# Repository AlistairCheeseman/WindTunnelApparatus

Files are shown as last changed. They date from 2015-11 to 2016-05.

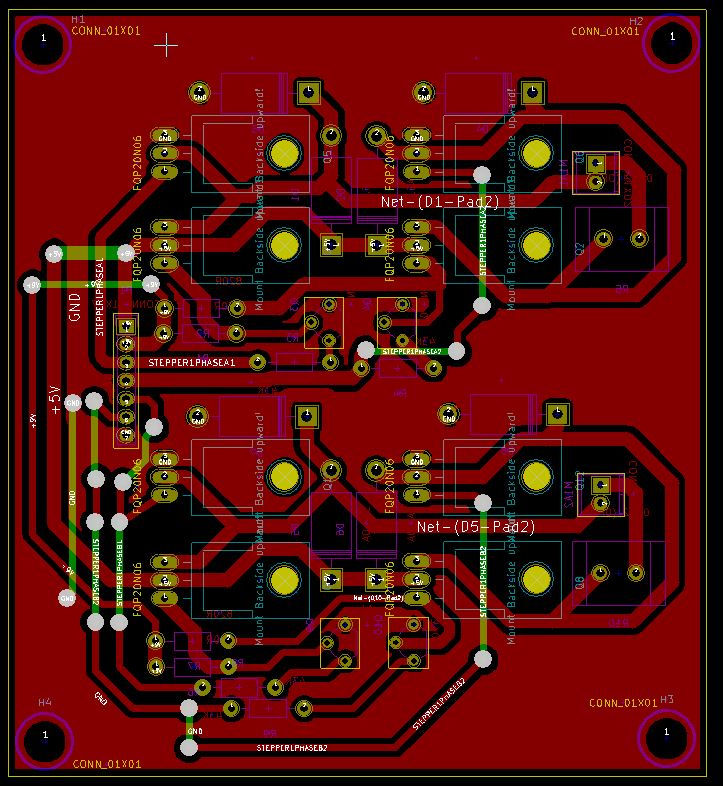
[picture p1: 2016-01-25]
Hardware/StepperDriver/Driver/Driver-PCB.JPG

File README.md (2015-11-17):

# WindTunnelApparatus
MENG Data Acquisition + motion control for Wind Tunnel Apparatus Project

There are three root folders in this repository:

Hardware  -  Contains hardware designs, files are created in KiCAD however relevant pdfs are provided.

Software  -  Contains software used on the Acquisition Computer

Firmware  -  Contains firmware source code, self explanatory

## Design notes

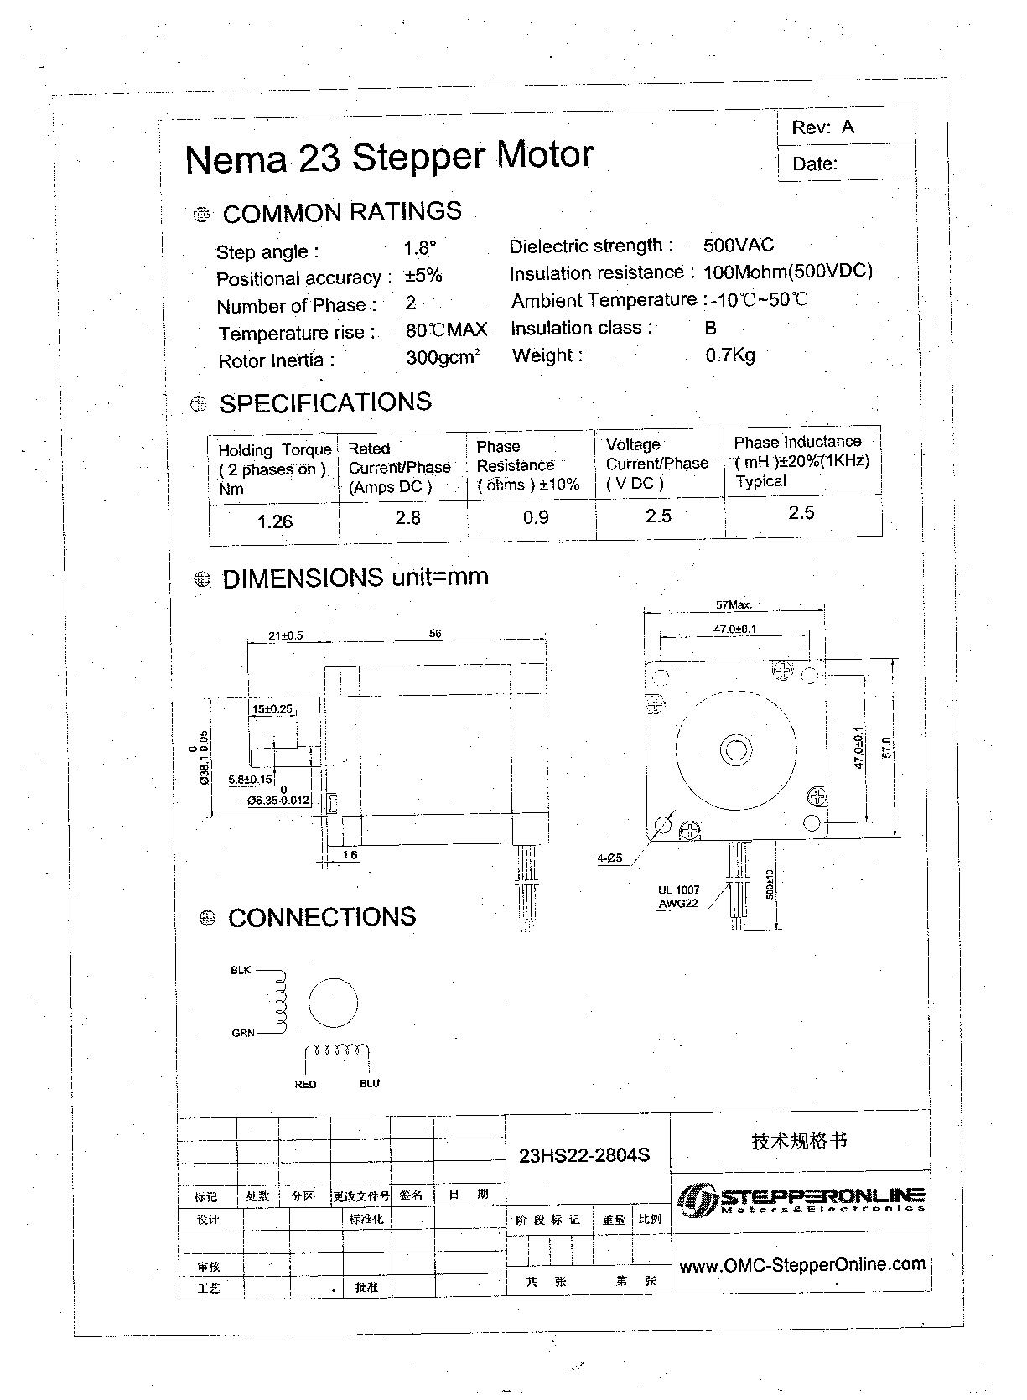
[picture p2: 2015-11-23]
Hardware/Datasheets/stepper.jpeg

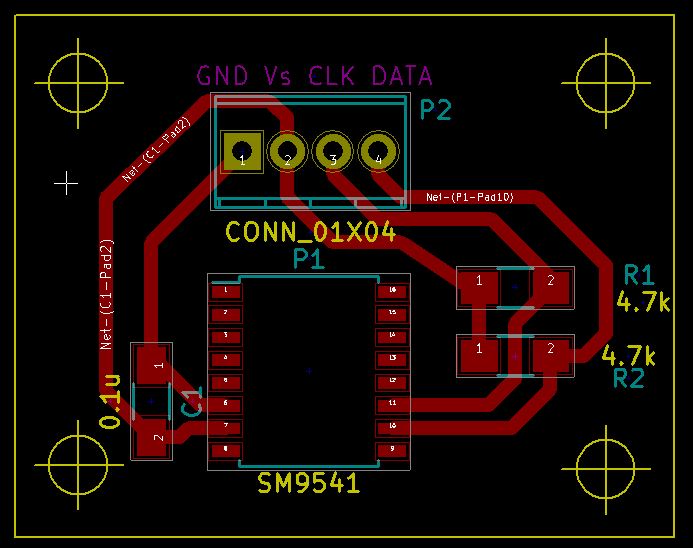
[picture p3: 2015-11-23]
Hardware/I2C/Rev2.JPG

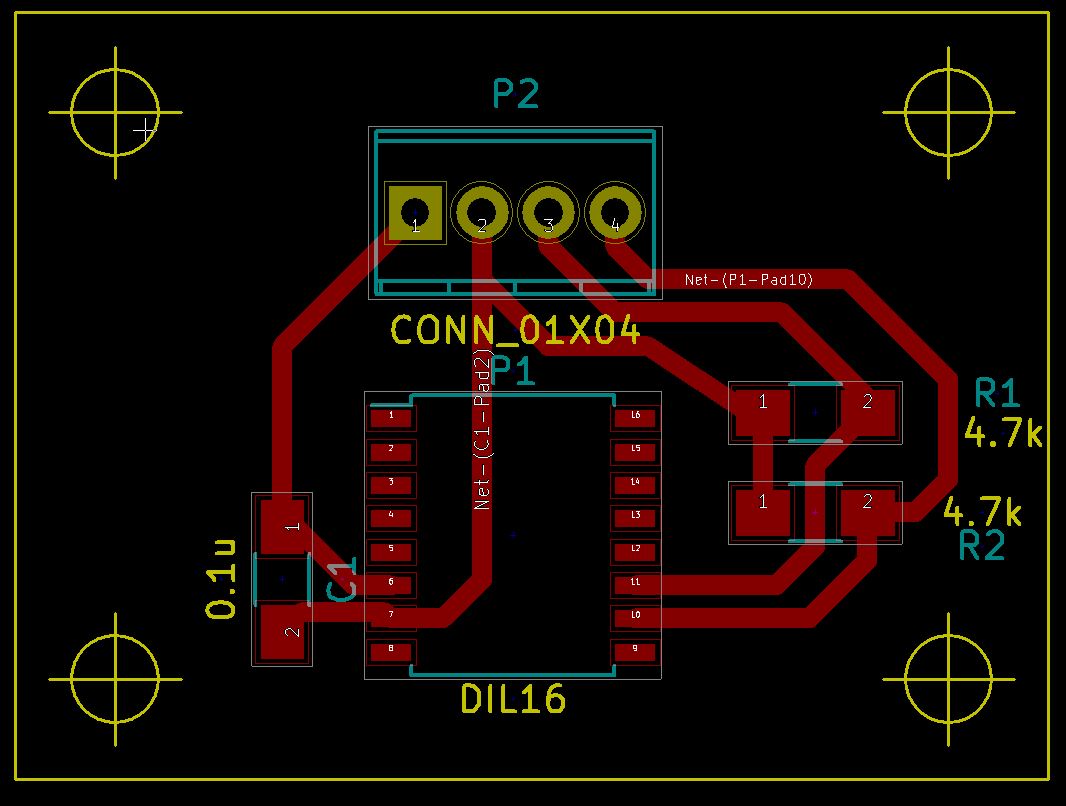
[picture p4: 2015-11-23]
Hardware/I2C/Rev1.JPG

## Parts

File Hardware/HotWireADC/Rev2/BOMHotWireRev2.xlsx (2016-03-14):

Reference | Value | Footprint | Datasheet
U5 | ADS8331 | Housings_SSOP:TSSOP-24_4.4x7.8mm_Pitch0.65mm
JP1 | JUMPER3 | Socket_Strips:Socket_Strip_Straight_1x03 |  |  |  |  | Mouser Part No | Mouser Link
U1 | OPA320 | TO_SOT_Packages_SMD:SOT-23-5 |  |  | ADS8331 | 1 | 595-ADS8331IPW (http://www.mouser.co.uk/Search/ProductDetail.aspx) | http://www.mouser.co.uk/Search/ProductDetail.aspx
U2 | OPA320 | TO_SOT_Packages_SMD:SOT-23-5 |  |  | OPA320 | 5 | 595-OPA320AIDBVR (http://www.mouser.co.uk/Search/ProductDetail.aspx) | http://www.mouser.co.uk/Search/ProductDetail.aspx
U3 | OPA320 | TO_SOT_Packages_SMD:SOT-23-5 |  |  | 40R | 4 | #NAME?
U4 | OPA320 | TO_SOT_Packages_SMD:SOT-23-5 |  |  | 1.5n | 4 | 77-VJ1206Y152KXXCBC (http://www.mouser.co.uk/Search/ProductDetail.aspx) | http://www.mouser.co.uk/Search/ProductDetail.aspx
R4 | 40R | Resistors_SMD:R_1206_HandSoldering |  |  | 10K | 4 | 71-CRCW1206-10K-E3 (http://www.mouser.co.uk/Search/ProductDetail.aspx) | http://www.mouser.co.uk/Search/ProductDetail.aspx
C4 | 1.5n | Capacitors_SMD:C_1206_HandSoldering |  |  | 34.8 | 1 | 667-ERJ-8ENF34R8V (http://www.mouser.co.uk/Search/ProductDetail.aspx) | http://www.mouser.co.uk/Search/ProductDetail.aspx
R3 | 40R | Resistors_SMD:R_1206_HandSoldering |  |  | 750p | 1 | 581-12065A751JAT2A (http://www.mouser.co.uk/Search/ProductDetail.aspx) | http://www.mouser.co.uk/Search/ProductDetail.aspx
C3 | 1.5n | Capacitors_SMD:C_1206_HandSoldering |  |  | SW_PUSH_SMALL | 1 | 506-2-1437565-8 (http://www.mouser.co.uk/Search/ProductDetail.aspx) | http://www.mouser.co.uk/Search/ProductDetail.aspx
R1 | 40R | Resistors_SMD:R_1206_HandSoldering |  |  | 0.1u | 2 | 77-VJ1206Y104KXBAT (http://www.mouser.co.uk/Search/ProductDetail.aspx) | http://www.mouser.co.uk/Search/ProductDetail.aspx
C1 | 1.5n | Capacitors_SMD:C_1206_HandSoldering |  |  | 1u | 4 | 77-VJ1206Y105KXQTBC (http://www.mouser.co.uk/Search/ProductDetail.aspx) | http://www.mouser.co.uk/Search/ProductDetail.aspx
R2 | 40R | Resistors_SMD:R_1206_HandSoldering |  |  | 10u | 4 | 77-VJ1206V106ZXQTBC (http://www.mouser.co.uk/Search/ProductDetail.aspx) | http://www.mouser.co.uk/Search/ProductDetail.aspx
C2 | 1.5n | Capacitors_SMD:C_1206_HandSoldering |  |  | 0.5R | 2 | 603-RL1206FR070R5L (http://www.mouser.co.uk/Search/ProductDetail.aspx) | http://www.mouser.co.uk/Search/ProductDetail.aspx
R5 | 10K | Resistors_SMD:R_1206_HandSoldering |  |  | REF5040 | 1 | 595-REF5040AIDR (http://www.mouser.co.uk/Search/ProductDetail.aspx) | http://www.mouser.co.uk/Search/ProductDetail.aspx
R7 | 34.8 | Resistors_SMD:R_1206_HandSoldering |  |  | 10u tant | 2 | 647-F931A106MAA (http://www.mouser.co.uk/Search/ProductDetail.aspx) | http://www.mouser.co.uk/Search/ProductDetail.aspx
C5 | 750p | Capacitors_SMD:C_1206_HandSoldering |  |  | L78S05 | 1 | 511-L78S05CV (http://www.mouser.co.uk/Search/ProductDetail.aspx?R=L78S05CVvirtualkey51120000virtualkey511-L78S05CV) | http://www.mouser.co.uk/Search/ProductDetail.aspx?R=L78S05CVvirtualkey51120000virtualkey511-L78S05CV
R6 | 10K | Resistors_SMD:R_1206_HandSoldering |  |  | BNC | 5 | 571-5-1634503-1 (http://www.mouser.co.uk/Search/ProductDetail.aspx) | http://www.mouser.co.uk/Search/ProductDetail.aspx
SW1 | SW_PUSH_SMALL | Buttons_Switches_SMD:SW_SPST_EVPBF |  |  | BARREL_JACK | 1 | 502-RASM712X (http://www.mouser.co.uk/Search/ProductDetail.aspx?R=RASM712Xvirtualkey50210000virtualkey502-RASM712X) | http://www.mouser.co.uk/Search/ProductDetail.aspx?R=RASM712Xvirtualkey50210000virtualkey502-RASM712X
C8 | 0.1u | Capacitors_SMD:C_1206_HandSoldering
C6 | 0.1u | Capacitors_SMD:C_1206_HandSoldering
C10 | 1u | Capacitors_SMD:C_1206_HandSoldering
C11 | 10u | Capacitors_SMD:C_1206_HandSoldering |  |  | Extra filter
R8 | 0.5R | Resistors_SMD:R_1206_HandSoldering |  |  | 22u | 1 | 581-1206ZG226ZAT2A (http://www.mouser.co.uk/Search/ProductDetail.aspx)
JP4 | JUMPER3 | Socket_Strips:Socket_Strip_Straight_1x03 |  |  | 0.22Ohm | 1 | 279-RL73K2BR22JTD (http://www.mouser.co.uk/Search/ProductDetail.aspx)
JP3 | JUMPER3 | Socket_Strips:Socket_Strip_Straight_1x03
JP2 | JUMPER | Socket_Strips:Socket_Strip_Straight_1x02
U8 | OPA320 | TO_SOT_Packages_SMD:SOT-23-5 |  |  | Kostas BNC connector |  | 571-1-1337543-0 (http://www.mouser.co.uk/Search/ProductDetail.aspx)
C14 | 10u | Capacitors_SMD:C_1206_HandSoldering
R10 | 0.5R | Resistors_SMD:R_1206_HandSoldering |  |  | 100ohm |  | 594-53611101 (http://www.mouser.co.uk/Search/ProductDetail.aspx?R=536B101virtualkey59400000virtualkey594-53611101)
C15 | 10u | Capacitors_SMD:C_1206_HandSoldering |  |  | 1k |  | 858-P160KN0QD15B1K (http://www.mouser.co.uk/Search/ProductDetail.aspx)
R9 | 10k | Resistors_SMD:R_1206_HandSoldering |  |  | 20k |  | 858-P160KN-0QC15B20K (http://www.mouser.co.uk/Search/ProductDetail.aspx)
R11 | 10K | Resistors_SMD:R_1206_HandSoldering
U9 | REF5040 | SMD_Packages:SOIC-8-N |  |  | knob for pot |  | 652-H-22-6A (http://www.mouser.co.uk/Search/ProductDetail.aspx?R=H-22-6Avirtualkey65210000virtualkey652-H-22-6A)
C17 | 1u | Capacitors_SMD:C_1206_HandSoldering
C16 | 10u | Capacitors_SMD:C_1206_HandSoldering |  | Rapid part no
C9 | 10u tant | Capacitors_Tantalum_SMD:TantalC_SizeU_EIA-6032 |  | 11-3438 | 4.7nF |  | 810-FG18X7R1H472KNT0 | http://www.mouser.co.uk/ProductDetail/TDK/FG18X7R1H472KNT00/
C12 | 10u tant | Capacitors_Tantalum_SMD:TantalC_SizeU_EIA-6032 |  | 11-3436 | 2.2nf |  | 810-FG18C0G1H222JNT6 | http://www.mouser.co.uk/ProductDetail/TDK/FG18C0G1H222JNT06/
C13 | 1u | Capacitors_SMD:C_1206_HandSoldering |  | 11-3433 | 470pf |  | 810-FG18C0G1H471JNT6 | http://www.mouser.co.uk/ProductDetail/TDK/FG18C0G1H471JNT06/
C7 | 1u | Capacitors_SMD:C_1206_HandSoldering |  | 11-3431 | 220pf |  | 810-FG18C0G1H221JNT6 | http://www.mouser.co.uk/ProductDetail/TDK/FG18C0G1H221JNT06/
U7 | L78S05 | CustomFootprints:TO-220_REGULATORVIGNDVO_Vertical_LargePads |  | 11-3409 | 150pf |  | 810-FG18C0G1H151JNT0 | http://www.mouser.co.uk/ProductDetail/TDK/FG18C0G1H151JNT00/
P3 | BNC | Connect:bnc-ci
P4 | BNC | Connect:bnc-ci
P1 | BNC | Connect:bnc-ci
P2 | BNC | Connect:bnc-ci |  |  | LM555CN |  | 512-LM555CN | http://www.mouser.co.uk/ProductDetail/Fairchild-Semiconductor/LM555CN/
P5 | CONN_02X06 | Socket_Strips:Socket_Strip_Straight_2x06
CON1 | BARREL_JACK | Connect:JACK_ALIM
P6 | BNC | Connect:bnc-ci

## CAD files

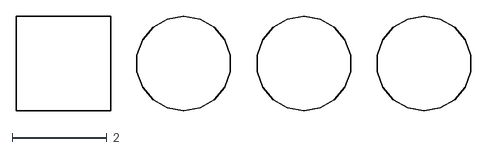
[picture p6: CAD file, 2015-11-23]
Hardware/I2C/I2C-B_Cu.dxf
9.61 x 2.00

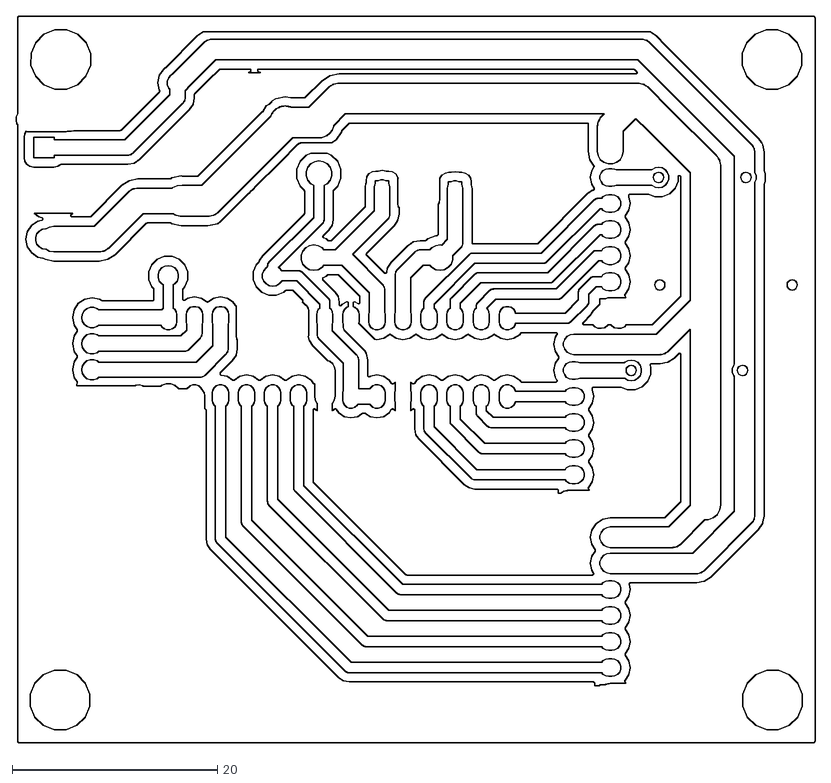
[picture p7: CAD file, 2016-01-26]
Hardware/StepperDriver/Brains/Brains-F.Cu.dxf
77.8 x 70.7

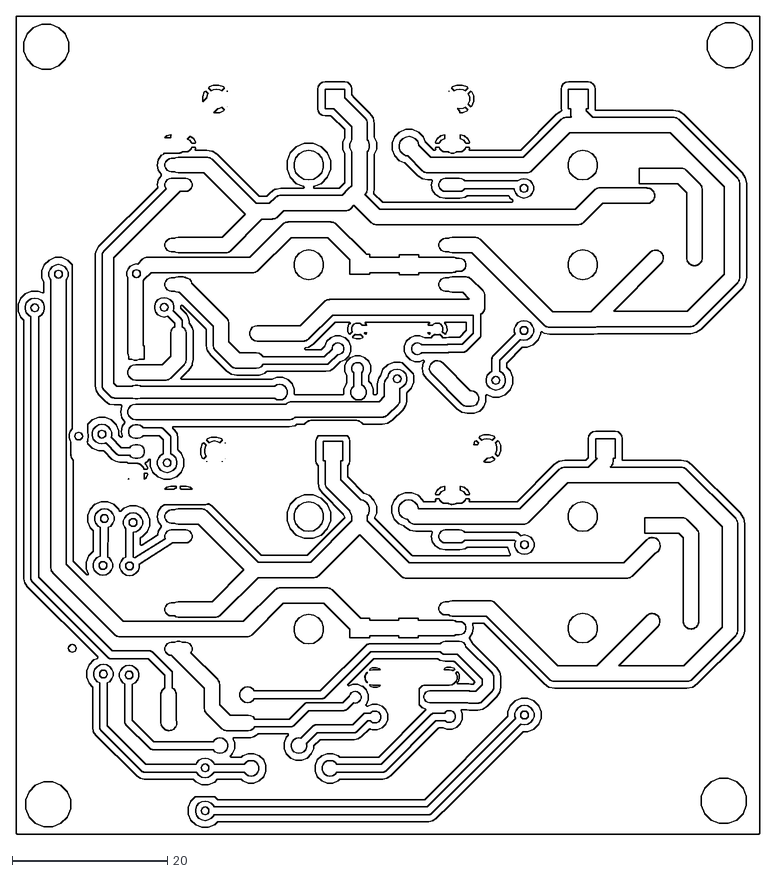
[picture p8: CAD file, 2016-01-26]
Hardware/StepperDriver/Driver/Driver-F.Cu.dxf
95.7 x 105.2

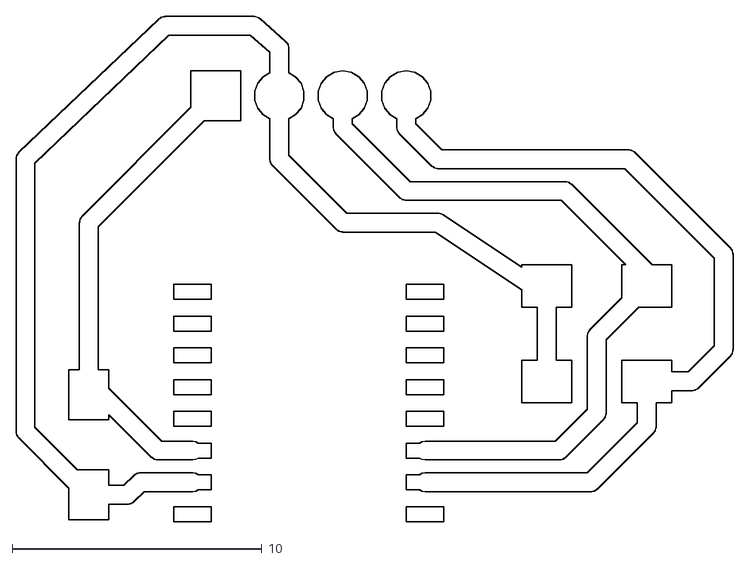
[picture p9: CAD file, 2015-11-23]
Hardware/I2C/I2C-F_Cu.dxf
28.7 x 20.2

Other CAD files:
Hardware/I2C/I2C-F_Cu_ISOLATION_GCODE.dxf

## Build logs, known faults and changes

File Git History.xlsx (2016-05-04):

Sat Apr 16 11:06:10 2016 | Merge branch 'master' of git@github.com:AlistairCheeseman/WindTunnelApparatus.git
Fri Apr 15 20:54:22 2016 | wired up pause button
Fri Apr 15 20:53:46 2016 | added pause capability. Added check to only request to update stepper motors if needed. move sensor acquisition to try catch expression to recover from bad readings
Fri Apr 15 20:49:35 2016 | updated option button typo. updated initial positions
Fri Apr 15 20:10:36 2016 | removed need to sign manifests
Fri Apr 15 19:56:58 2016 | increased delay to increase torque to motor.
Mon Apr 11 17:46:51 2016 | added extra marks and alignment to PCB for silkscreen
Sun Apr 10 14:44:46 2016 | FIXED MASSIVE BUG IN EXPORT DATA ROUTINE
Sun Apr 10 12:45:35 2016 | Merge branch 'master' of git@github.com:AlistairCheeseman/WindTunnelApparatus.git
Sun Apr 10 12:44:54 2016 | added abort routine.
Sun Apr 10 12:34:50 2016 | ensured current sensor readings - by setting readings to 0 before processing readings recreated queue to allow for re-connections
Sun Apr 10 12:28:21 2016 | added atmospheric pressures and temperatures to VM and export. removed background worker and replaced with async method to get better timing of system. changed from foreach to index array addressing due to too many records causing crash. used new export method using new averaging values. changed data model to use averaging.
Sun Apr 10 11:54:02 2016 | updated export routine to use array access instead of foreach as foreach cannot handle large numbers of records. added trap to only record data if a variable is true if not it just updates the UI.
Sun Apr 10 11:45:26 2016 | changed location of zero on axis. reduced motor delay -- imcreased motor speed. disabled Console updates of serial log
Thu Apr 7 22:53:43 2016 | added enviromental conditions box to UI
Thu Apr 7 22:53:00 2016 | shortened acceleration time in stepper algorithm
Wed Apr 6 14:34:17 2016 | implemented new DC jack footprint
Wed Apr 6 13:16:22 2016 | updated schematic to use correct DC jack footprint
Wed Apr 6 13:03:23 2016 | created smd jack in library
Mon Apr 4 15:56:49 2016 | updated file types and added wired up automation cancel button
Mon Apr 4 15:56:15 2016 | fixed spacing typo
Mon Apr 4 15:54:30 2016 | added busy flag to automation controller. took advantage of pressure export id continuation function. fixed missing delimeter on export. added check to prevent creation of empty files.
Mon Apr 4 15:53:13 2016 | updated dialog to remove file extensio values. also added alert to show export completed.
Mon Apr 4 15:52:33 2016 | added details to serial port exception. implelented a start value to the export sorter function
Mon Apr 4 15:51:11 2016 | changed pressureexport data to long - to account for long running times
Mon Apr 4 15:50:50 2016 | updated stepper baud rate and updated a lot of hard coded values to constants. added limit location functionality. fixed Y axis direction issue.
Mon Apr 4 15:49:03 2016 | added default values for this particular wind tunnel
Mon Apr 4 15:48:41 2016 | increased serial speed. added fix to ask for limit location when initialising
Sun Apr 3 23:24:25 2016 | added quick fix to see if stepper motor controller is connected and implemented settle time wait
Sun Apr 3 17:32:14 2016 | updated stimulus generator routine to export settle time.
Sun Apr 3 17:31:38 2016 | updated gitignore for VS2015R2
Sun Apr 3 14:26:36 2016 | updated ui to show units
Sun Apr 3 14:26:24 2016 | added settle time to measurement class
Sun Apr 3 13:05:00 2016 | added new parameter to ui - time for flow to settle
Sun Apr 3 12:35:06 2016 | created basic full export routine - to be tested
Sun Apr 3 12:23:28 2016 | moved export data to central DataClasses - moved export preperation to static routine to expose for automation controller
Thu Mar 31 16:32:38 2016 | Merge branch 'master' of git@github.com:AlistairCheeseman/WindTunnelApparatus.git
Thu Mar 31 16:30:35 2016 | filled out basic functionality to hot wire controller class
Thu Mar 31 16:26:42 2016 | added simple interrupt script example for potential expansion of stepper controller
Thu Mar 31 13:36:09 2016 | added queue status to menu form
Thu Mar 31 13:07:26 2016 | wired up hot wire controller
Thu Mar 31 13:01:45 2016 | removed unneeded comments/debug info
Mon Mar 28 15:50:43 2016 | updated gitignore for c++ projects
Mon Mar 28 15:50:28 2016 | created c++ programs to simulate the sensors
Mon Mar 28 14:36:01 2016 | tied up automation events to prompt user for save file dialog. tied up Hotwire connections. fixed file open dialog cancel bug
Mon Mar 28 14:17:55 2016 | plugged into automation event.
Mon Mar 28 14:14:34 2016 | moved data containers to DataClasses. made clearer regions in class. Added completion events
Mon Mar 28 14:10:00 2016 | updated binding expressions to be more uniform and complete.
Mon Mar 28 14:09:23 2016 | created basic Hotwire controller class - non functional at the moment. just scaffolding
Mon Mar 28 13:53:48 2016 | updated to routine to correctly work according to step distance
Mon Mar 28 13:49:58 2016 | added clearer zero command
Sat Mar 19 15:02:26 2016 | updated published version
Thu Mar 17 20:51:21 2016 | updated UI properties for the new automationController structure added stimulus menu option
Thu Mar 17 20:49:15 2016 | moved controllers to automation container. made automationcontroller use background worker to keep UI thread responsive. moved some properties to the automationcontroller
Thu Mar 17 20:32:06 2016 | updated positional data to read in microns fixed axis typo. set motor to not move after axis zero.
Thu Mar 17 20:18:13 2016 | updated loop counts to ensure accurate step counts
Thu Mar 17 14:13:16 2016 | indented file.
Thu Mar 17 14:12:55 2016 | added clause to ensure that no steps are taken on a 0 step command.
Thu Mar 17 10:59:02 2016 | added automationcontroller class to mainviewmodel. added measurement information properties. added Loadstimulus and executemeasurementcycle functions
Thu Mar 17 10:54:05 2016 | added positional updates to stepper controller. Added gotoXY support.
Thu Mar 17 10:51:31 2016 | added very basic automation controller.
Thu Mar 17 10:45:18 2016 | meade measurements public
Thu Mar 17 10:44:56 2016 | added infographic to solution and added stimulus generator to project- hardcoded for 10%
Thu Mar 17 10:43:45 2016 | updated published software version
Thu Mar 17 10:43:30 2016 | added position updates to stepper controller firmware
Tue Mar 15 21:12:25 2016 | Merge branch 'master' of git@github.com:AlistairCheeseman/WindTunnelApparatus.git
Tue Mar 15 21:12:07 2016 | added datasheet for DC barrel connector
Tue Mar 15 21:11:13 2016 | added datasheet for high side driver transistor
Tue Mar 15 20:57:31 2016 | Merge branch 'master' of git@github.com:AlistairCheeseman/WindTunnelApparatus.git
Tue Mar 15 20:55:44 2016 | switched to custom delay routine due to arduino delay functions being so bad
Mon Mar 14 18:58:05 2016 | tidied layout added text to silk added mounting holes and alignment marks
Mon Mar 14 18:57:20 2016 | added parts needed for BOM + parts from other HotWire hardware ( maintained by different user)
Sun Mar 13 20:02:12 2016 | increased track widths.
Sun Mar 13 19:49:45 2016 | updated component names and created BOM
Sun Mar 13 19:07:57 2016 | updated regulator footprint and removed additional regulator
Sun Mar 13 18:43:46 2016 | moved external reference to BNC connector & tidied layout
Sun Mar 13 17:55:21 2016 | created intial PCB layout
Sun Mar 13 14:57:11 2016 | added footprints to schematic
Sat Mar 12 16:33:09 2016 | Merge branch 'master' of git@github.com:AlistairCheeseman/WindTunnelApparatus.git
Sat Mar 12 16:32:49 2016 | fixed incorrect sensor count update. made serialiser buffer bigger fixed typo on temperature calculation
Sat Mar 12 16:29:36 2016 | created initial design and added relevant datasheets
Fri Mar 11 13:59:18 2016 | moved HotWireADC hardware files to revision structure - due to complete design change
Fri Mar 4 20:23:30 2016 | deployed new version to be installed
Fri Mar 4 18:38:30 2016 | updated calculations to use double instead of decimal to speed processing time. added additional worker to seperate data into packets. updated indents added queue status indicators
Fri Mar 4 18:21:17 2016 | updated to compile program as 64x
Fri Mar 4 09:23:58 2016 | Merge branch 'master' of git@github.com:AlistairCheeseman/WindTunnelApparatus.git
Fri Mar 4 09:23:18 2016 | created peek and get functions for dequeuing functions. moved to an async file writer
Fri Mar 4 09:19:08 2016 | increased timeout window to prevent multiple loops, also removed timeout from sensor 1. this fixes timing of the loops, but means that sensor 1 will ALWAYS have to be connected
Wed Mar 2 18:57:45 2016 | completely re-worked data sequencer to work better with 2+ sensors
Wed Mar 2 18:56:29 2016 | completely re-worked data processing routine. routine now runs on two worker processes to crunch data. Increased OS receive buffer size.
Wed Mar 2 18:42:35 2016 | created testbench for the DataSequencer for more thorough test scenarios
Wed Mar 2 18:38:42 2016 | created custom part for ADC component.
Tue Mar 1 08:50:23 2016 | created hotwire ADC pcb project
Tue Mar 1 08:50:00 2016 | added moment (datetime reading) and Id (unique number) to pressure data class.
Tue Mar 1 08:49:31 2016 | added check to make sure stepper controller was connected before sending job commands. removed dispatcher assignment. added timer to update UI elements
Tue Mar 1 08:48:28 2016 | added x and y stepper info, removed excess hot wire readings.
Tue Mar 1 08:48:04 2016 | added x and y position to stepper controller
Tue Mar 1 08:46:43 2016 | updated project to use new file location
Sat Feb 27 22:11:07 2016 | updated main view to show current sensor readings and status. wired up additional buttons
Sat Feb 27 21:55:22 2016 | indented class added update to make the controllers initialise on startup. added HotWireFunctions added notify property update routines
Sat Feb 27 21:52:47 2016 | added lastest sensor reading properties with update. added regions added connection state property with update. removed dispatcher allocation on creation and moved to set dispatcher routine added routine to skip error on unrecoverable partial error.
Sat Feb 27 21:48:39 2016 | extracted speed routine to seperate subroutine to allow for easier modification
Sat Feb 27 21:29:04 2016 | added connection state updates.
Sat Feb 27 21:22:26 2016 | added sensorId to pressureData class
Sat Feb 27 21:21:36 2016 | mods to stepper controller: | removed unused dispatcher | added ViewModelBase helper class | converted isConnected and isBusy to properties with notifications
Sat Feb 27 20:16:58 2016 | enabled multiple values for connection state.
Sat Feb 27 20:09:58 2016 | added viwemodelbase class to add and simplify notifications of updated properties.
Sat Feb 27 20:08:08 2016 | completely re-wrote to remove multiplexers. Seems to have stabilised the sensor array packets and removed a lot of warnings in synthesis.
Sat Feb 27 10:27:23 2016 | updated delay to be easier to edit and decreased delay.
Sat Feb 27 10:26:16 2016 | updated console display from debug to actual
Fri Feb 26 21:50:52 2016 | updated to 10 transducer code. still needs testing.
Fri Feb 26 21:43:35 2016 | updated Pressure Data class to more appropriate names, also added additional data elements. updated processing routine to process new 6 byte header.Also added better header handling - for future updates.
Thu Feb 25 19:12:21 2016 | updated simulation to match new signal naming conventions
Thu Feb 25 17:25:01 2016 | updated pinout to be compatible with array PCB and also used pin names featuring sensorID
Thu Feb 25 17:14:52 2016 | temporarily removed unused ports. updated to use correct ports for SCL and SDA. Removed rw and addr from I2C control as constant so will not need changing.
Wed Feb 24 09:31:42 2016 | added state and implemented sensor id byte added to payload.
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

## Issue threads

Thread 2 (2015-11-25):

Optimise Timestamping method

AlistairCheeseman, 2015-11-25:
At current data is timestampled when it is processed, this could be improved as there may be a small jitter caused by the current method

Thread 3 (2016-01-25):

Diode footprint on driver board too small

AlistairCheeseman, 2016-01-25:
tested pcb with all components, found doides are wrong footprint

AlistairCheeseman, 2016-01-25:
fixed to new footprints also fixed layer issue. implemented in 433cff479b10eea18f1bf91cb0aa96b0f408b8ed

Closed 2016-01-25.

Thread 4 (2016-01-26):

Implement STATE_RESET in seralLoader state machine

AlistairCheeseman, 2016-01-26:
currently serialLoader.chd does not implement any reset handling causing the serial loader to end up out of sync with the rest of the cpu. effects are only that rubbish ( 1 byte max) is spewed onto the serial line

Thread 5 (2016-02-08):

when half stepping rotation change issue

AlistairCheeseman, 2016-02-08:
half stepping is implemented by two variables, the current step and the previous step. when the direction is changed the previous step becomes the next step breaking the logic, when changing direction whilst half stepping will need to simply shift the previous step variable( now next step value) back to a correct value  ( previous step)

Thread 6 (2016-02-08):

implement step_mode change -- Affects - rotation change

AlistairCheeseman, 2016-02-08:
need to write routine to allow changing from one step mode to another, note will need to ensure all variables updated according to current motor posn - OR could re-zero on step change OR force one step mode.
note - linked issue https://github.com/AlistairCheeseman/WindTunnelApparatus/issues/5

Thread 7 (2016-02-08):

need to determine pressure transducer flags

AlistairCheeseman, 2016-02-08:
when multiplexing data from each pressure transducer onto the serial tx buffer various flags will be added, they need to be decided upon.
current delimeters needed:
  - some kind of ID as the what sensor # the data is
  - delimeter between each value
  - delimeter between each time series value

note: is it easier to simply tx every value with one delimiter opposed to two (as pressure data not time sensitive)? will make simpler and reduce data overhead.

AlistairCheeseman, 2016-02-08:
data efficiency:
byte 1 - sensor ID
byte 2 - status + (pressure [15:8]
byte 3 - rest of pressure data [7:0]
byte 4 - Temp [ 10:3]
byte 5 - Temp [2:0] --NOTE WASTED DATA SPACE
byte 6 - DELIMTER - must be whole byte for serial processor to recognise it
6 byte total, 27 bits data, Comms efficiency =  56.2%

AlistairCheeseman, 2016-02-08:
data efficiency(other method):
byte 1 - sensor ID
byte 2 - status + (pressure [15:8]
byte 3 - rest of pressure data [7:0]
byte 4 - Temp [ 10:3]
byte 5 - Temp [2:0] --NOTE WASTED DATA SPACE
byte 6 - DELIMTER - must be whole byte for serial processor to recognise it
.....
byte n-1 Temp(sensor10)[2:0]
byte n ROW DELIMETER

assuming 10 sensors, (6*10) = 60 bytes data
60 byte total, 270 bits data, Comms efficiency = 56.2%
does not acct for time stamp
same efficiency as above method HOWEVER if including time stamp this method will be more efficient

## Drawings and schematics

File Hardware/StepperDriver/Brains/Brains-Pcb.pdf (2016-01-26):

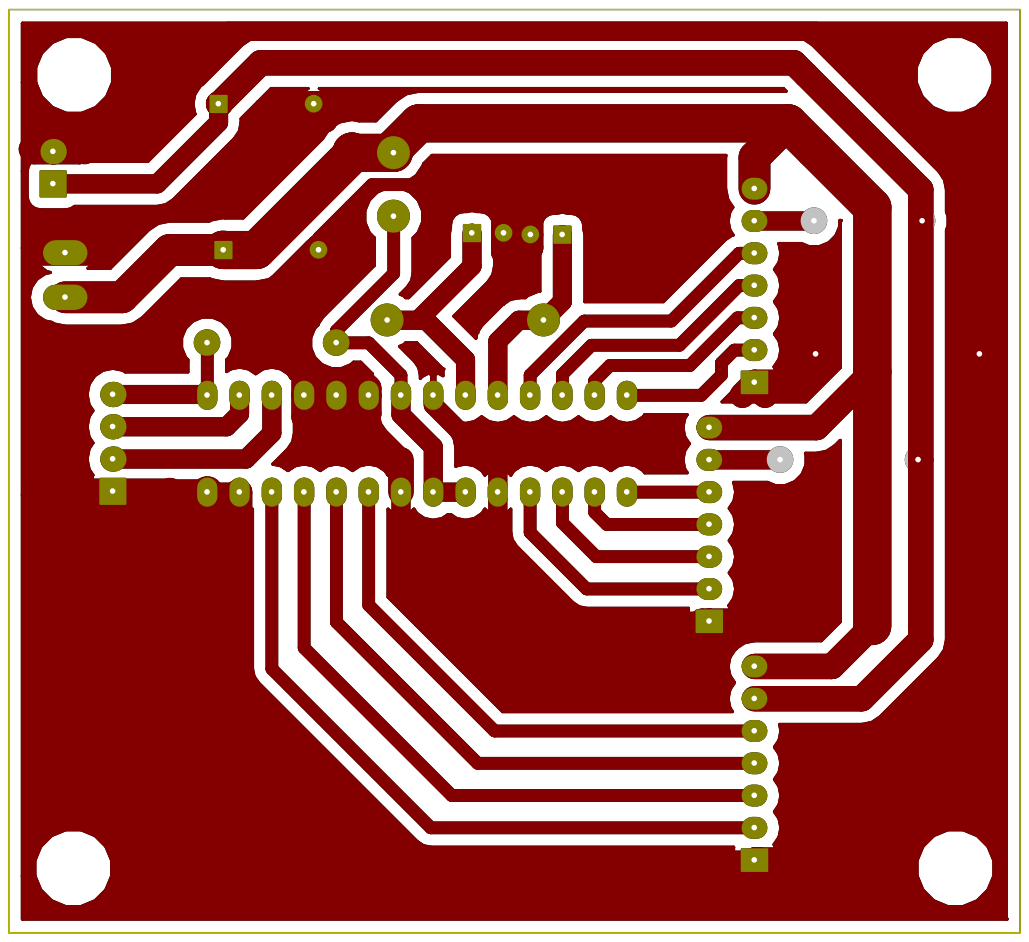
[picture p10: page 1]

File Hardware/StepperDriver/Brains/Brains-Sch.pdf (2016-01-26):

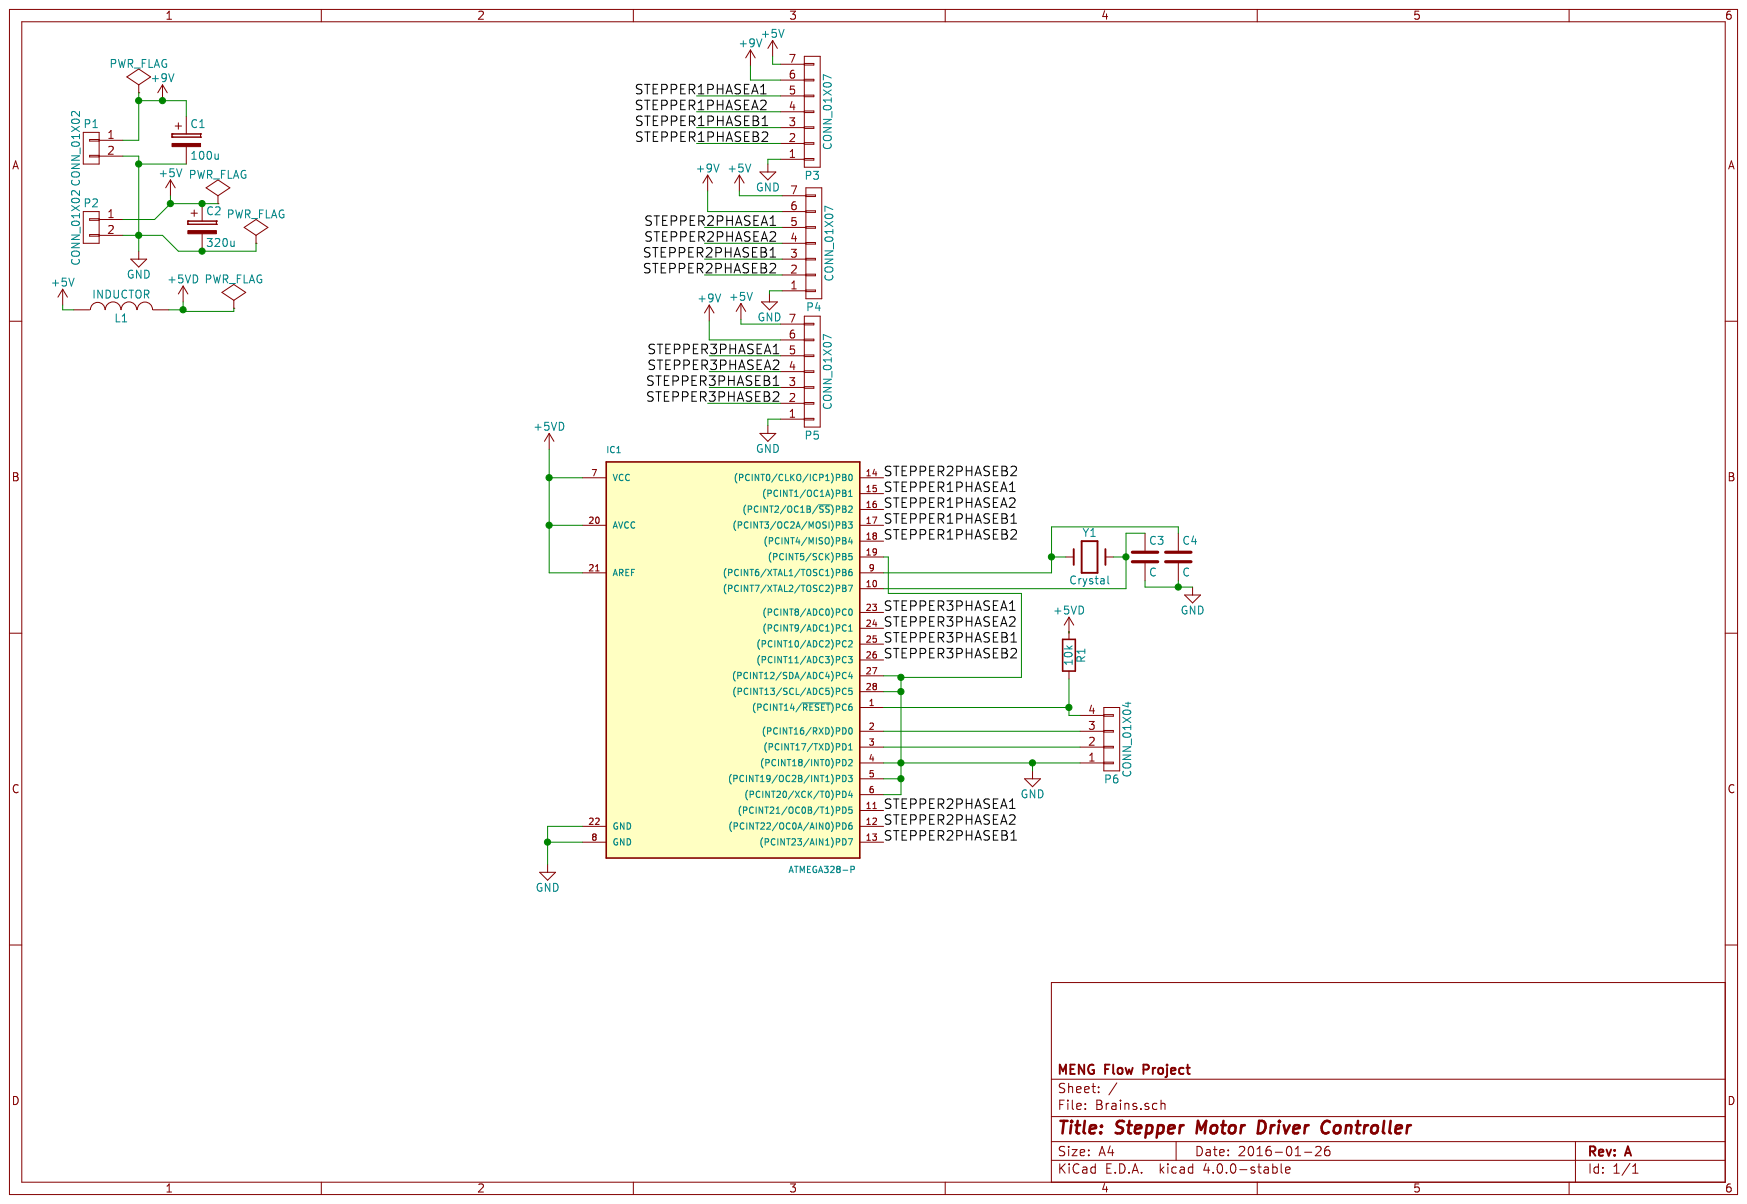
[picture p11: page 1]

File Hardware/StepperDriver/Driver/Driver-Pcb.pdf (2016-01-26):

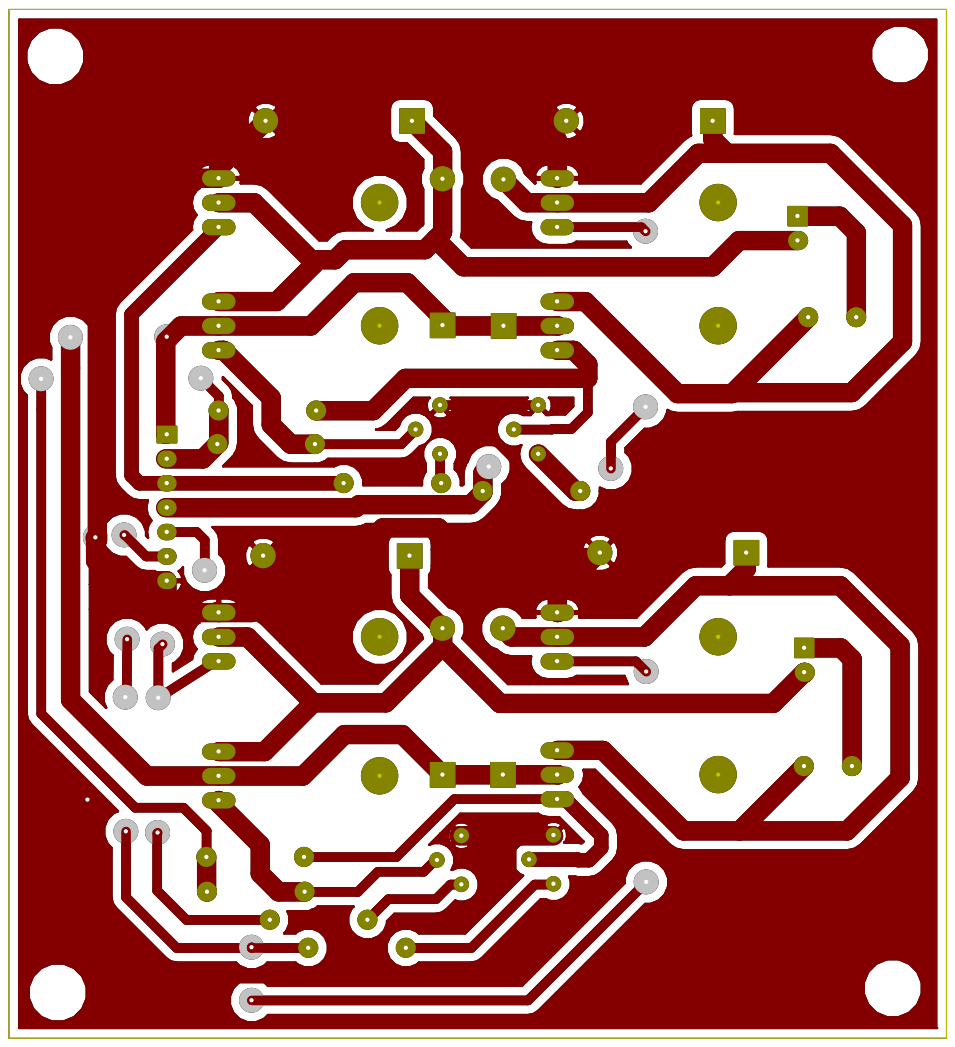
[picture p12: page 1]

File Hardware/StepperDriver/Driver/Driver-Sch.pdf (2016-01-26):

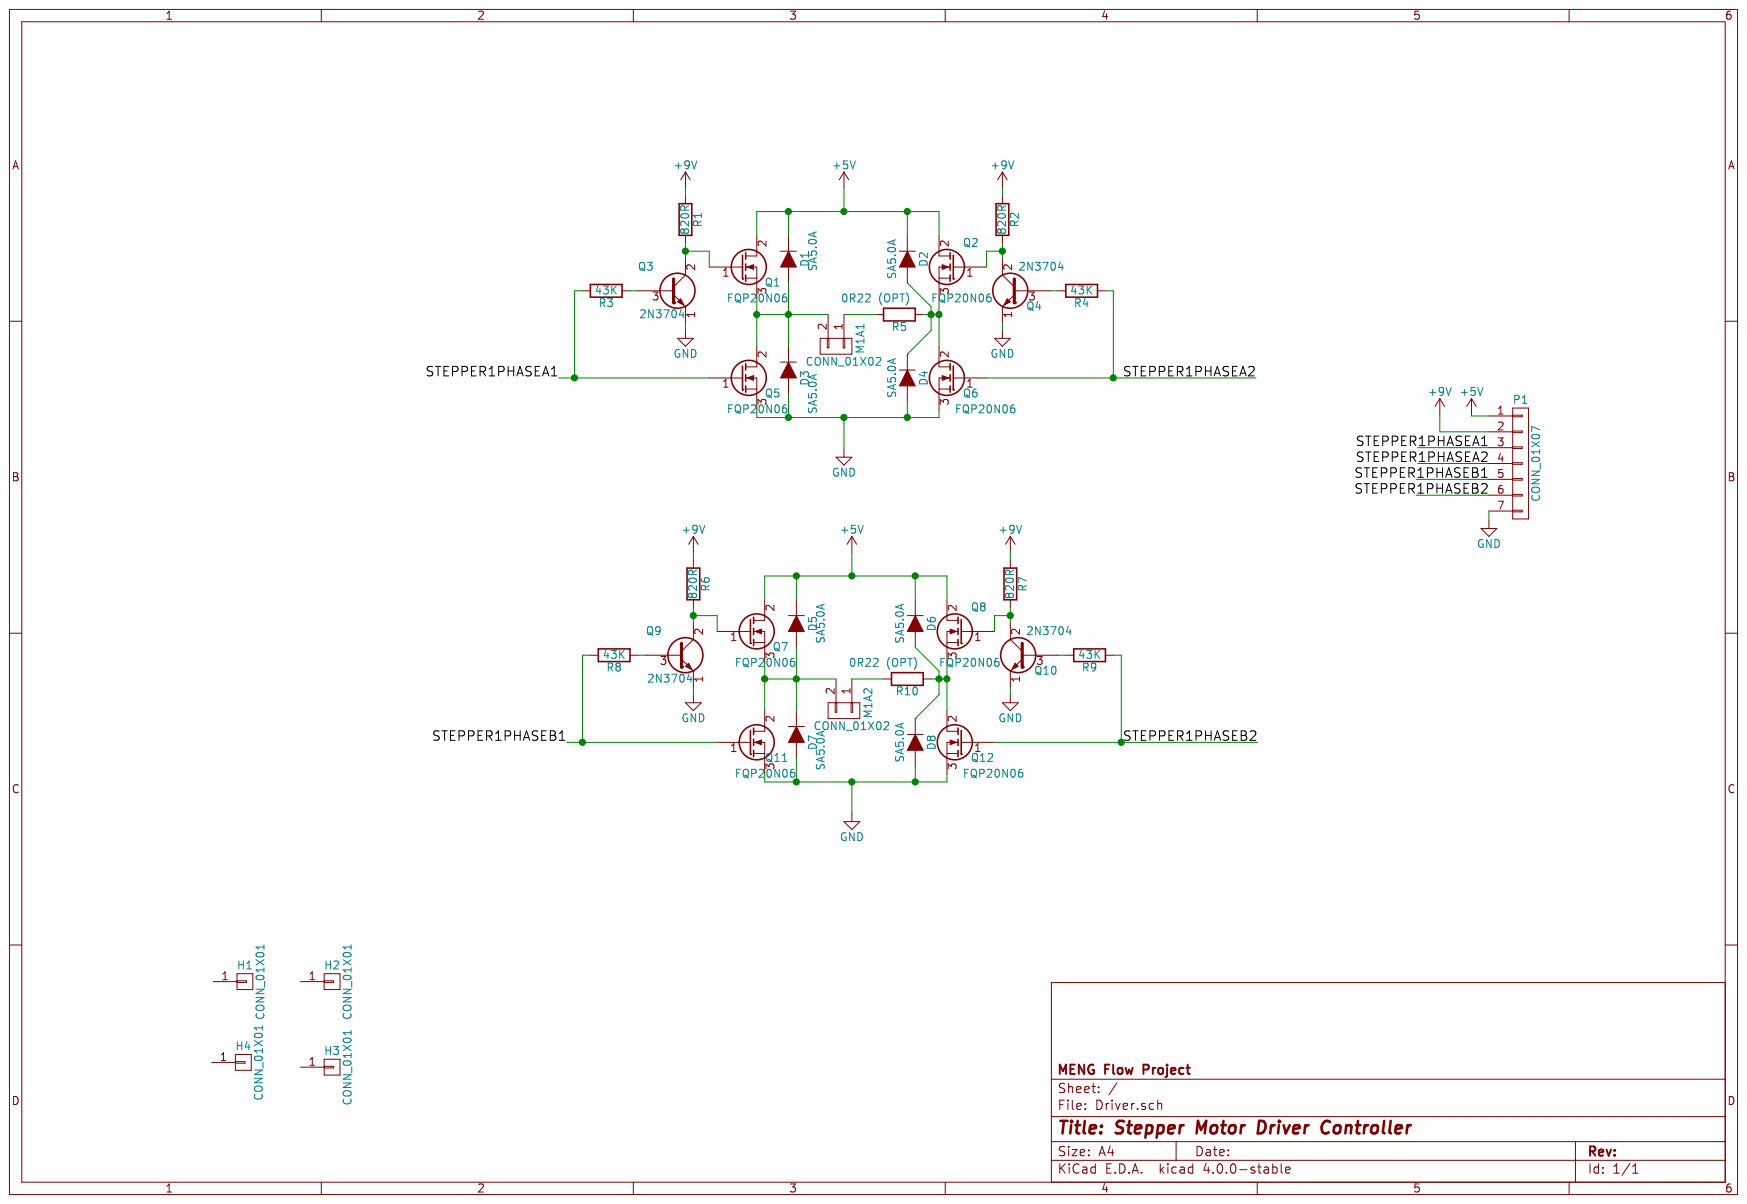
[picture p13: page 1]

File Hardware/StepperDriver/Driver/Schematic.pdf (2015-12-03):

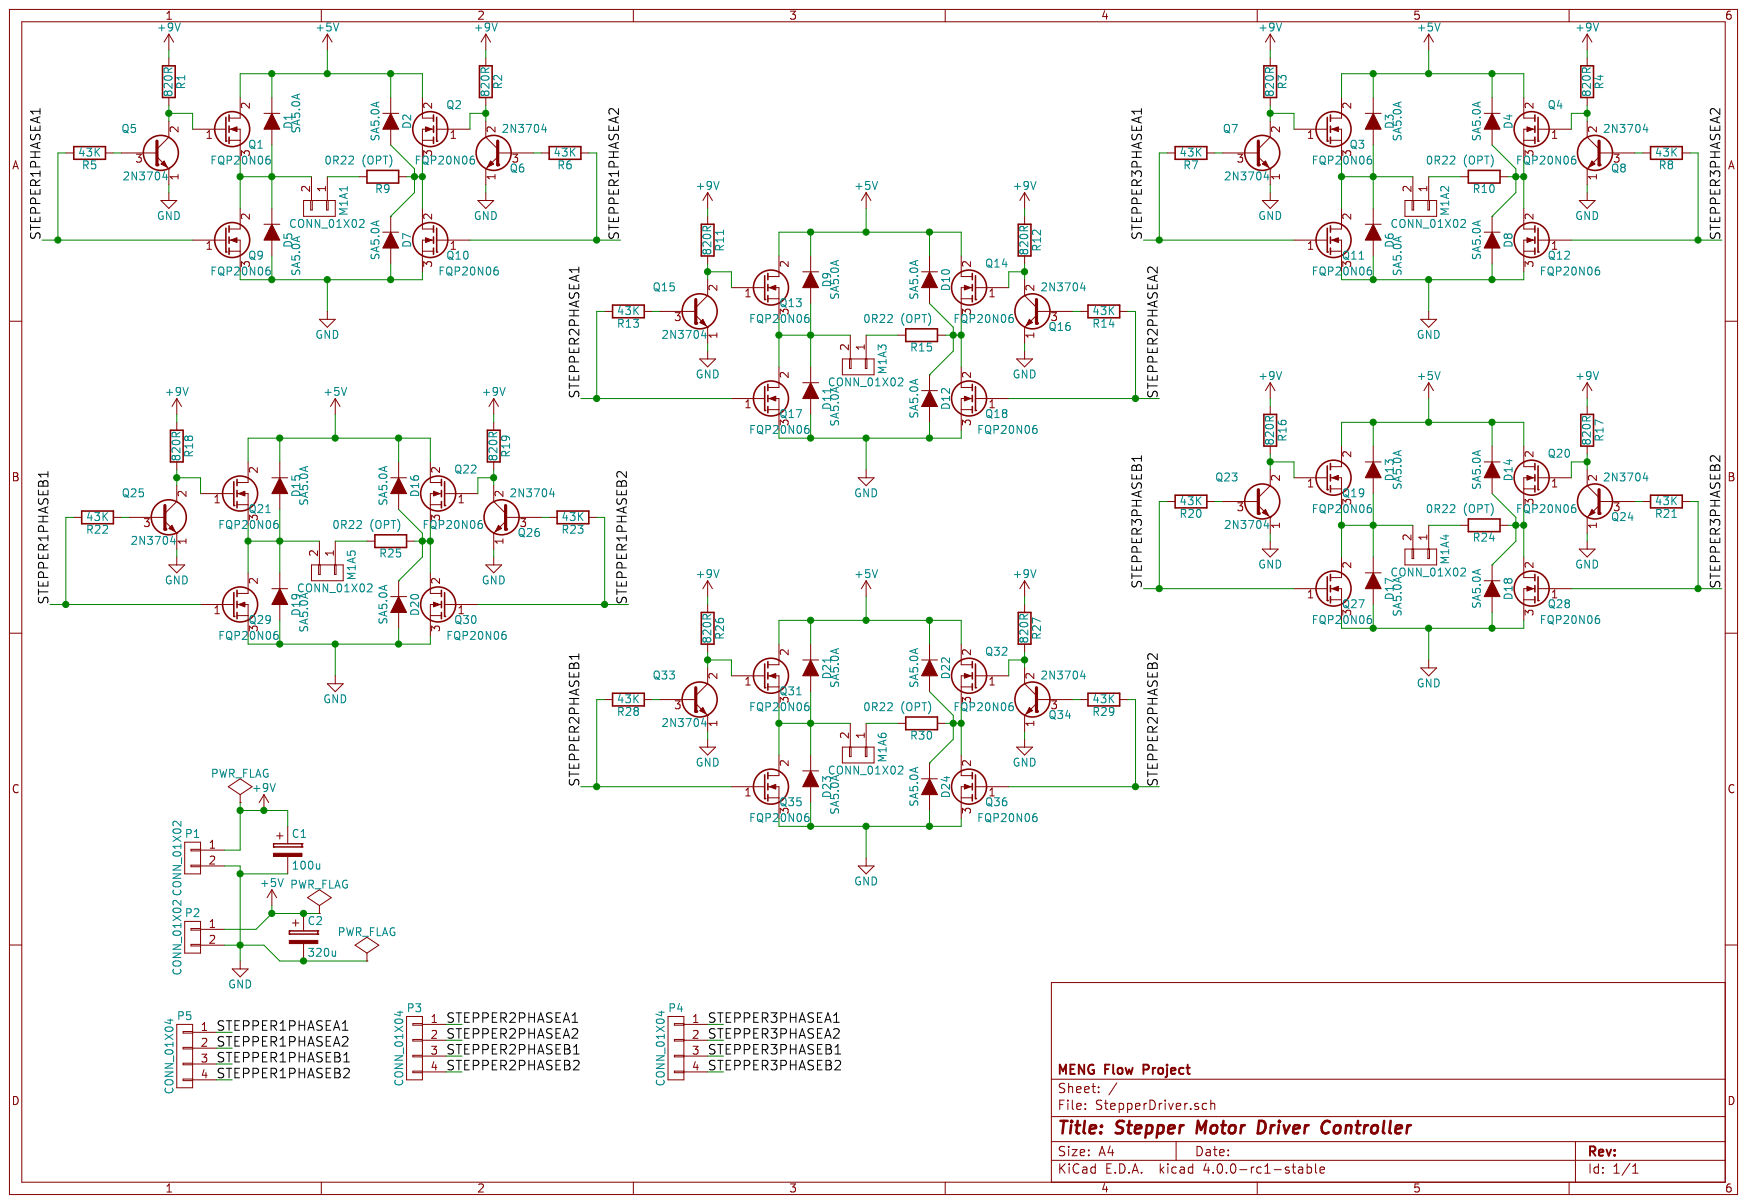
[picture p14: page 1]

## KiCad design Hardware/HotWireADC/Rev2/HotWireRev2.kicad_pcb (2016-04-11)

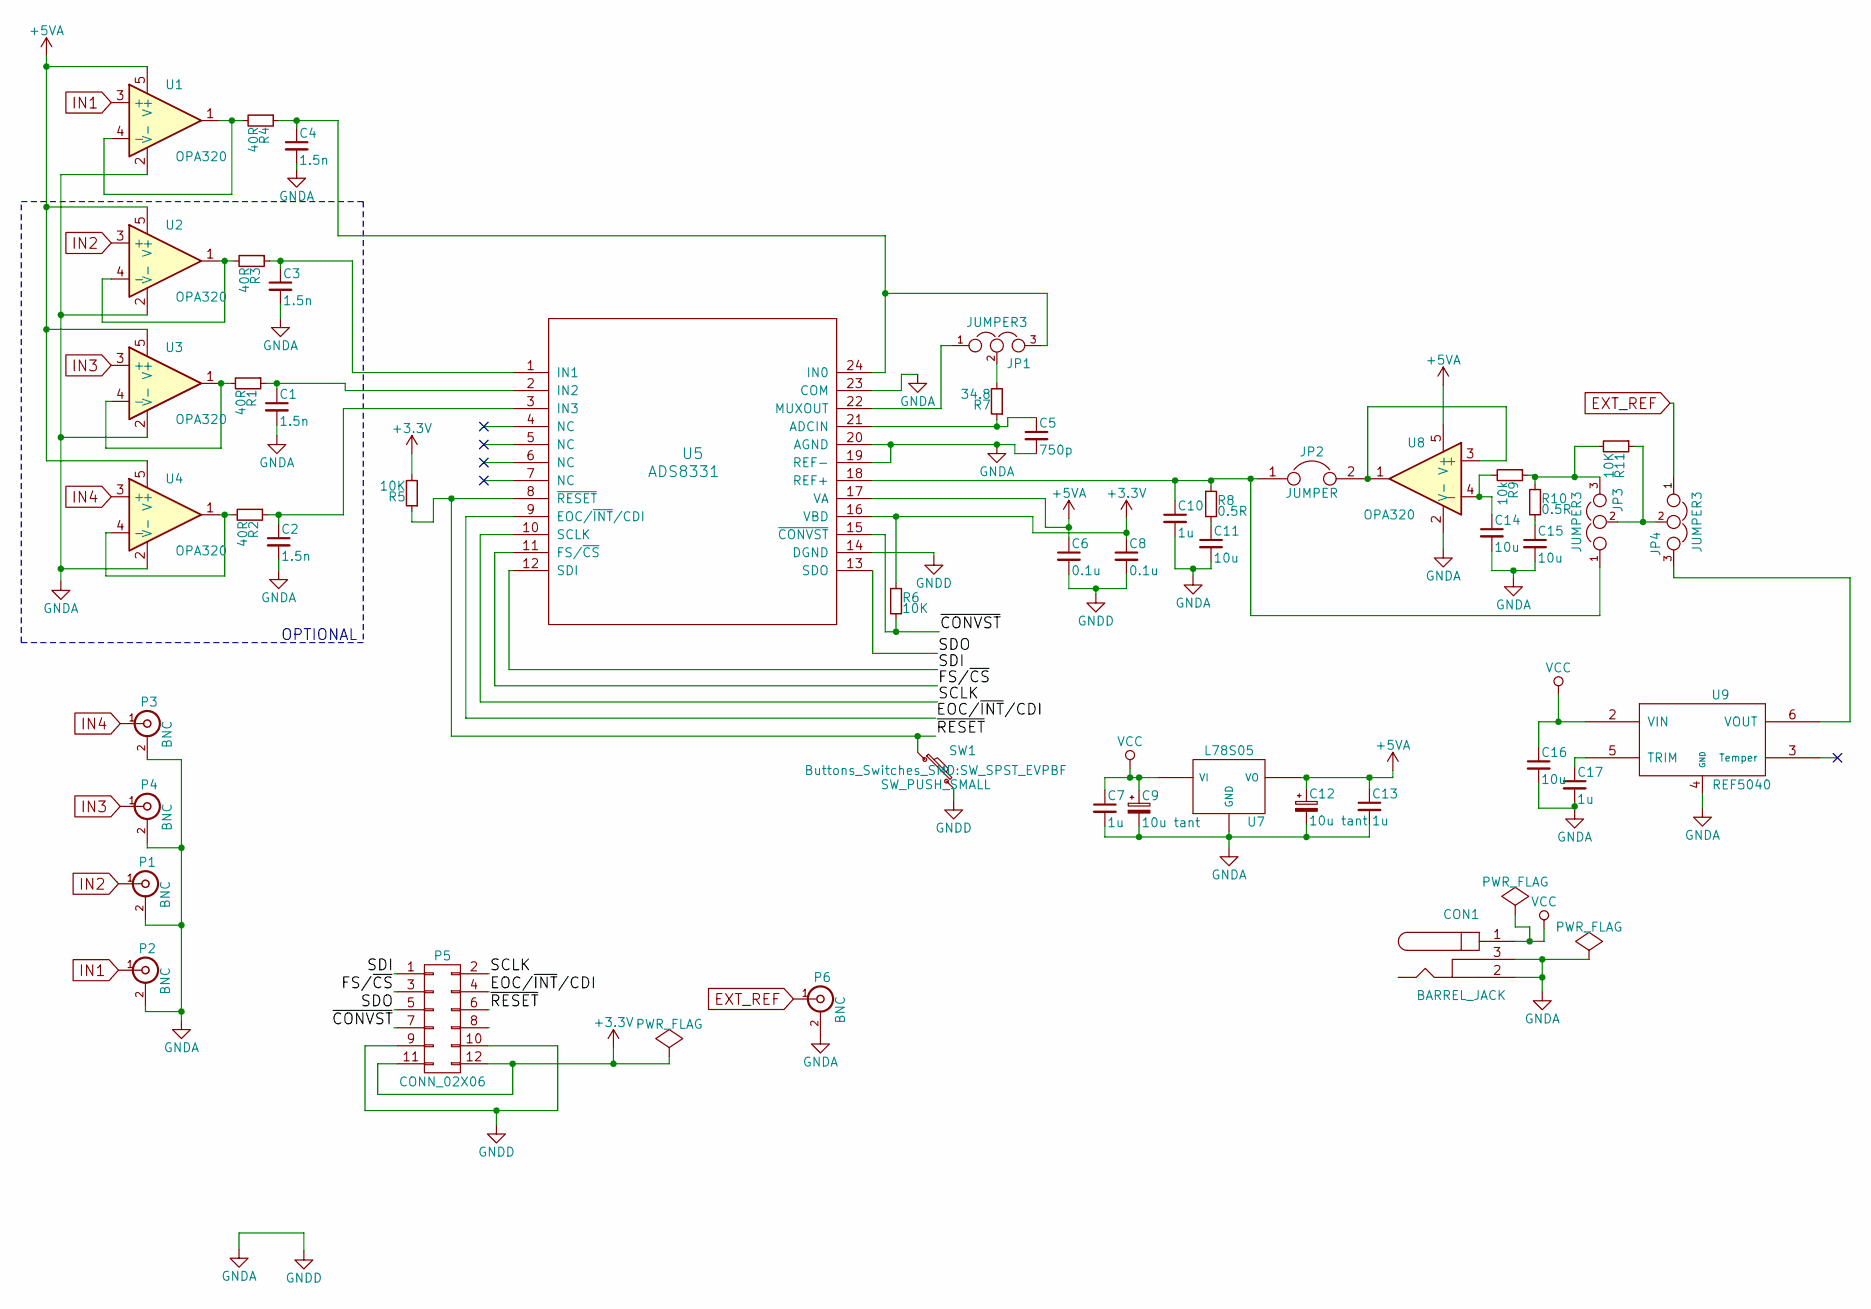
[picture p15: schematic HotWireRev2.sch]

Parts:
C1, C2, C3, C4: 1.5n; C_1206_HandSoldering
C5: 750p; C_1206_HandSoldering
C6, C8: 0.1u; C_1206_HandSoldering
C7, C10, C13, C17: 1u; C_1206_HandSoldering
C9, C12: 10u tant; TantalC_SizeU_EIA-6032
C11, C14, C15, C16: 10u; C_1206_HandSoldering
CON1: BARREL_JACK; JACK_SMD
JP1, JP3, JP4: JUMPER3; Socket_Strip_Straight_1x03
JP2: JUMPER; Socket_Strip_Straight_1x02
P1, P2, P3, P4, P6: BNC; bnc-ci
P5: CONN_02X06; Socket_Strip_Straight_2x06
R1, R2, R3, R4: 40R; R_1206_HandSoldering
R5, R6, R11: 10K; R_1206_HandSoldering
R7: 34.8; R_1206_HandSoldering
R8, R10: 0.5R; R_1206_HandSoldering
R9: 10k; R_1206_HandSoldering
SW1: SW_PUSH_SMALL; SW_SPST_EVPBF
U1, U2, U3, U4, U8: OPA320; SOT-23-5
U5: ADS8331; TSSOP-24_4.4x7.8mm_Pitch0.65mm
U7: L78S05; TO-220_REGULATORVIGNDVO_Vertical_LargePads
U9: REF5040; SOIC-8-N

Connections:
+3V3: C8.1, P5.11, P5.12, R5.2, R6.1, U5.16 (VBD)
+5VA: C6.1, C12.1, C13.1, U1.5 (V+), U2.5 (V+), U3.5 (V+), U4.5 (V+), U5.17 (VA), U7.VO, U8.5 (V+)
/EOC/~INT~/CDI: P5.4, U5.9 (EOC/~INT~/CDI)
/FS/~CS: P5.3, U5.11 (FS/~CS)
/SCLK: P5.2, U5.10 (SCLK)
/SDI: P5.1, U5.12 (SDI)
/SDO: P5.5, U5.13 (SDO)
/~CONVST: P5.7, R6.2, U5.15 (~CONVST)
/~RESET: P5.6, R5.1, SW1.1, U5.8 (~RESET)
EXT_REF: JP4.1, P6.1 (In)
GNDA: C1.2, C2.2, C3.2, C4.2, C5.2, C6.2, C7.2, C8.2, C9.2, C10.2, C11.2, C12.2, C13.2, C14.2, C15.2, C16.2, C17.2, CON1.2, CON1.3, P1.2 (Ext), P2.2 (Ext), P3.2 (Ext), P4.2 (Ext), P5.9, P5.10, P6.2 (Ext), SW1.2, U1.2 (V-), U2.2 (V-), U3.2 (V-), U4.2 (V-), U5.14 (DGND), U5.19 (REF-), U5.20 (AGND), U5.23 (COM), U7.GND, U8.2 (V-), U9.4 (GND)
IN1: P2.1 (In), U1.3 (+)
IN2: P1.1 (In), U2.3 (+)
IN3: P4.1 (In), U3.3 (+)
IN4: P3.1 (In), U4.3 (+)
unnamed: C1.1, R1.1, U5.2 (IN2)
unnamed: C2.1, R2.1, U5.3 (IN3)
unnamed: C3.1, R3.1, U5.1 (IN1)
unnamed: C4.1, JP1.3, R4.1, U5.24 (IN0)
unnamed: C5.1, R7.1, U5.21 (ADCIN)
unnamed: C10.1, JP2.1, JP3.1, R8.1, U5.18 (REF+)
unnamed: C11.1, R8.2
unnamed: C14.1, R9.2, U8.4 (-)
unnamed: C15.1, R10.2
unnamed: C17.1, U9.5 (TRIM)
unnamed: JP1.1, U5.22 (MUXOUT)
unnamed: JP1.2, R7.2
unnamed: JP2.2, U8.1, U8.3 (+)
unnamed: JP3.2, JP4.2, R11.1
unnamed: JP3.3, R9.1, R10.1, R11.2
unnamed: JP4.3, U9.6 (VOUT)
unnamed: R1.2, U3.1, U3.4 (-)
unnamed: R2.2, U4.1, U4.4 (-)
unnamed: R3.2, U2.1, U2.4 (-)
unnamed: R4.2, U1.1, U1.4 (-)
VCC: C7.1, C9.1, C16.1, CON1.1, U7.VI, U9.2 (VIN)

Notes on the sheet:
OPTIONAL

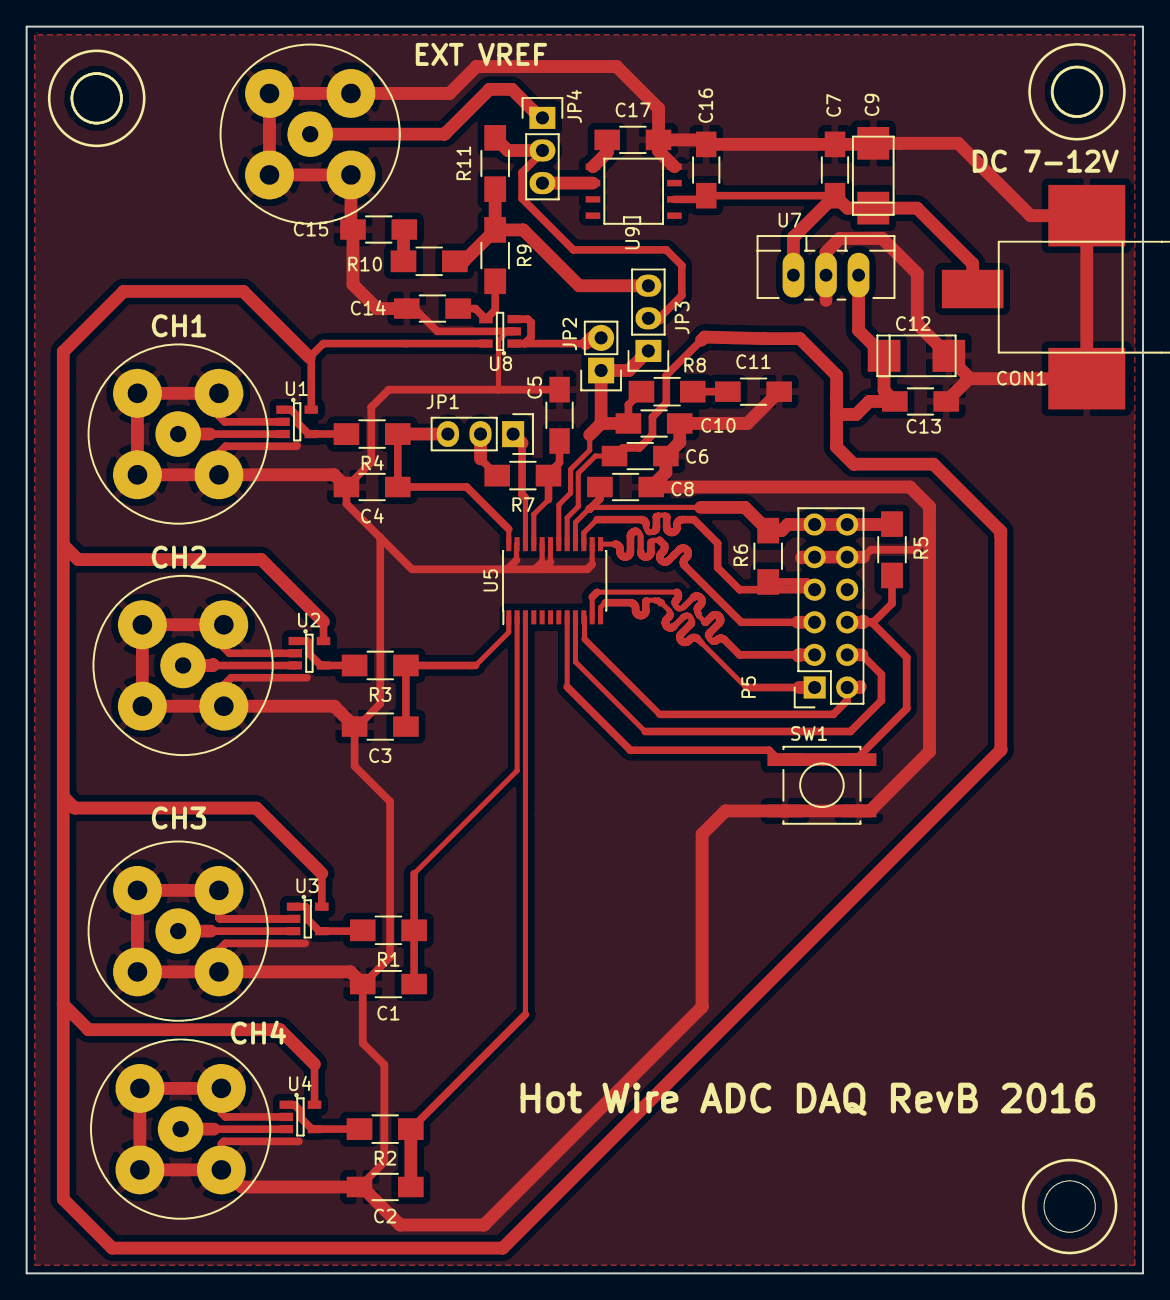
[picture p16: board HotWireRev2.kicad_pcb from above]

Board: 2 copper layers, 87.0 x 97.2 mm, 48 parts (0 on the bottom side), 36 nets.

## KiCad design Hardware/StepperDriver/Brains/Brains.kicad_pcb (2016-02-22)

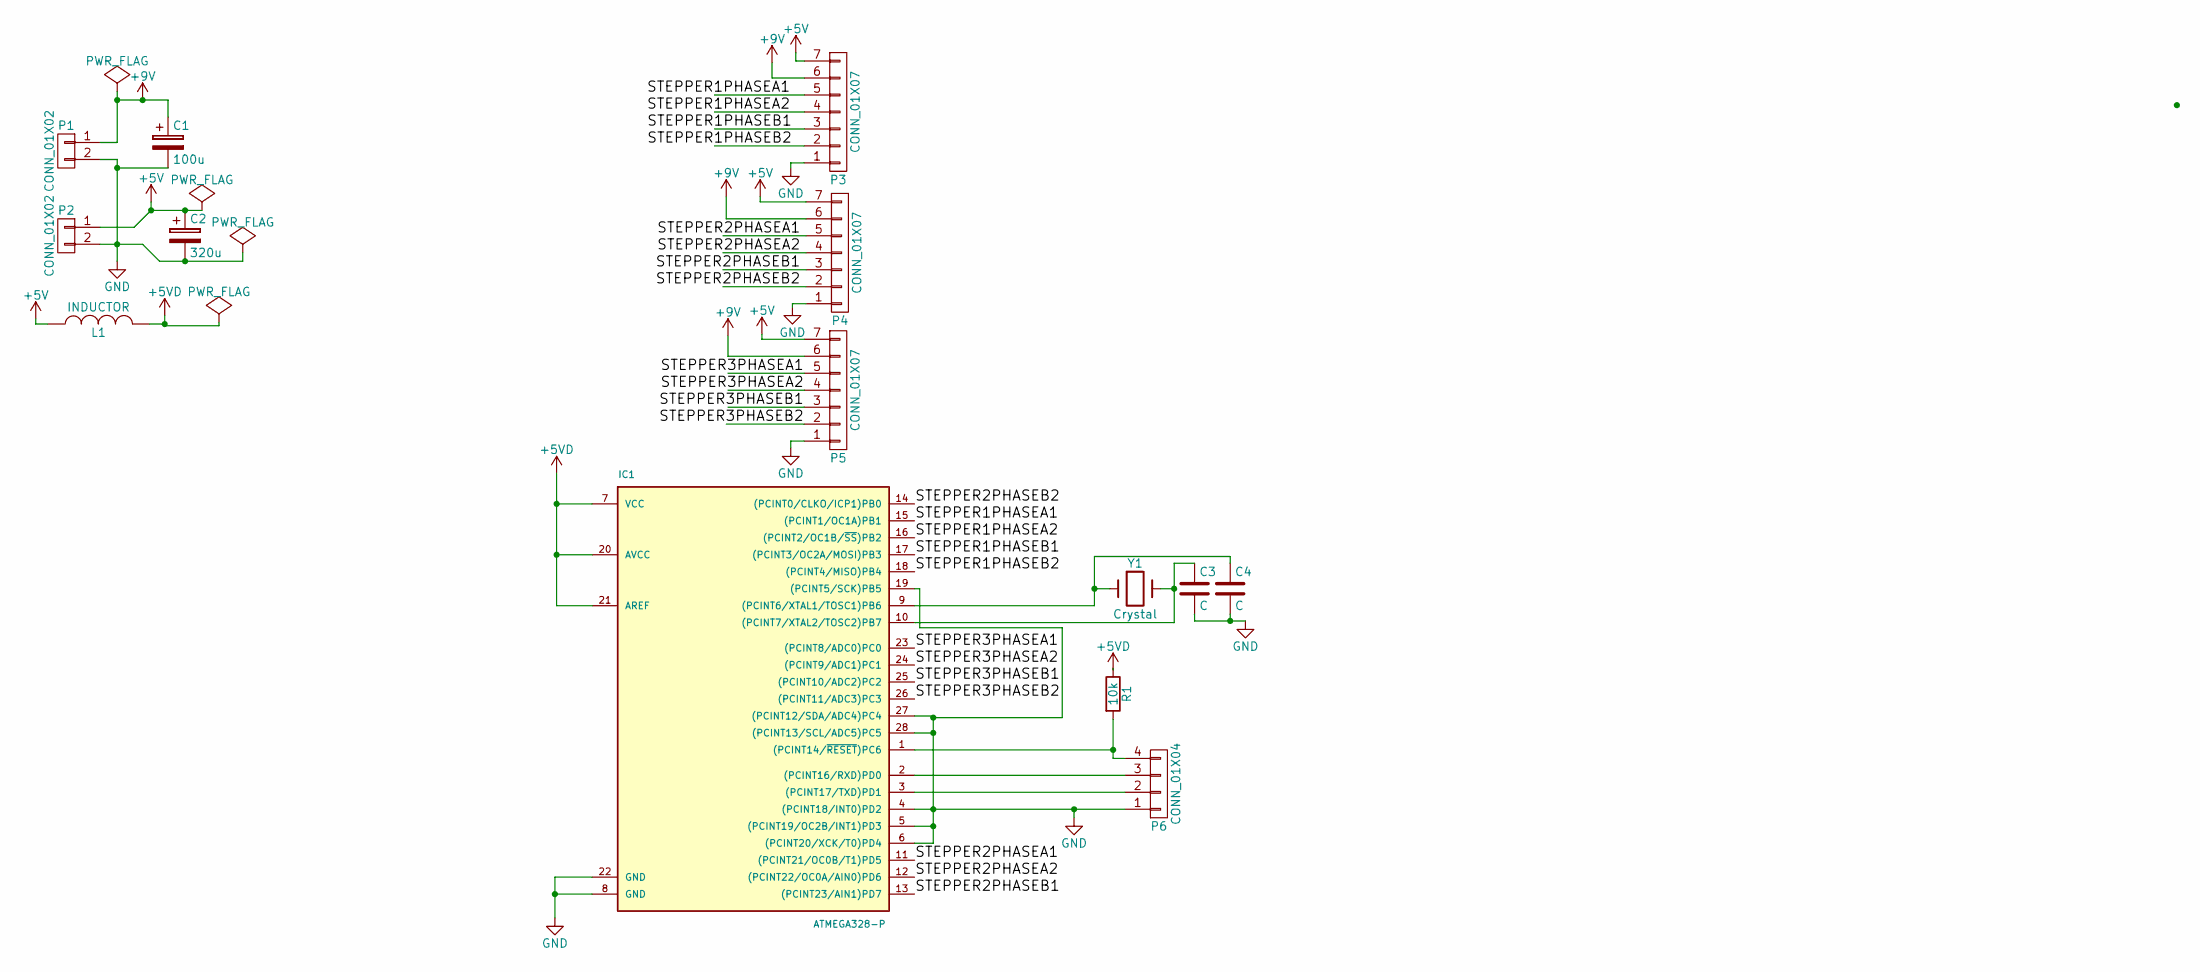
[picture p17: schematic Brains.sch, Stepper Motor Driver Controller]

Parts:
C1: 100u; C_Radial_D10_L20_P7.5
C2: 320u; C_Radial_D10_L20_P7.5
C3, C4: C; C_Disc_D3_P2.5
IC1: ATMEGA328-P; DIP-28_W7.62mm_LongPads
L1: INDUCTOR; Neosid_Inductor_Sd12k-style3
P1: CONN_01X02; TerminalBlock_Pheonix_MPT-2.54mm_2pol
P2: CONN_01X02; WAGO_734_2pin_Straight_RuggedPads
P3, P4, P5: CONN_01X07; Pin_Header_Straight_1x07
P6: CONN_01X04; TerminalBlock_Pheonix_MPT-2.54mm_4pol
R1: 10k; Resistor_Horizontal_RM10mm
Y1: Crystal; Crystal_HC49-U_Vertical

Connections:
+5V: C2.1, L1.1, P2.1, P3.7, P4.7, P5.7
+5VD: IC1.7 (VCC), IC1.20 (AVCC), IC1.21 (AREF), L1.2, R1.1
+9V: C1.1, P1.1, P3.6, P4.6, P5.6
/STEPPER1PHASEA1: IC1.15 ((PCINT1/OC1A)PB1), P3.5
/STEPPER1PHASEA2: IC1.16 ((PCINT2/OC1B/~SS~)PB2), P3.4
/STEPPER1PHASEB1: IC1.17 ((PCINT3/OC2A/MOSI)PB3), P3.3
/STEPPER1PHASEB2: IC1.18 ((PCINT4/MISO)PB4), P3.2
/STEPPER2PHASEA1: IC1.11 ((PCINT21/OC0B/T1)PD5), P4.5
/STEPPER2PHASEA2: IC1.12 ((PCINT22/OC0A/AIN0)PD6), P4.4
/STEPPER2PHASEB1: IC1.13 ((PCINT23/AIN1)PD7), P4.3
/STEPPER2PHASEB2: IC1.14 ((PCINT0/CLKO/ICP1)PB0), P4.2
/STEPPER3PHASEA1: IC1.23 ((PCINT8/ADC0)PC0), P5.5
/STEPPER3PHASEA2: IC1.24 ((PCINT9/ADC1)PC1), P5.4
/STEPPER3PHASEB1: IC1.25 ((PCINT10/ADC2)PC2), P5.3
/STEPPER3PHASEB2: IC1.26 ((PCINT11/ADC3)PC3), P5.2
GND: C1.2, C2.2, C3.2, C4.2, IC1.4 ((PCINT18/INT0)PD2), IC1.5 ((PCINT19/OC2B/INT1)PD3), IC1.6 ((PCINT20/XCK/T0)PD4), IC1.8 (GND), IC1.19 ((PCINT5/SCK)PB5), IC1.22 (GND), IC1.27 ((PCINT12/SDA/ADC4)PC4), IC1.28 ((PCINT13/SCL/ADC5)PC5), P1.2, P2.2, P3.1, P4.1, P5.1, P6.1
unnamed: C3.1, IC1.10 ((PCINT7/XTAL2/TOSC2)PB7), Y1.2
unnamed: C4.1, IC1.9 ((PCINT6/XTAL1/TOSC1)PB6), Y1.1
unnamed: IC1.1 ((PCINT14/~RESET~)PC6), P6.4, R1.2
unnamed: IC1.2 ((PCINT16/RXD)PD0), P6.3
unnamed: IC1.3 ((PCINT17/TXD)PD1), P6.2

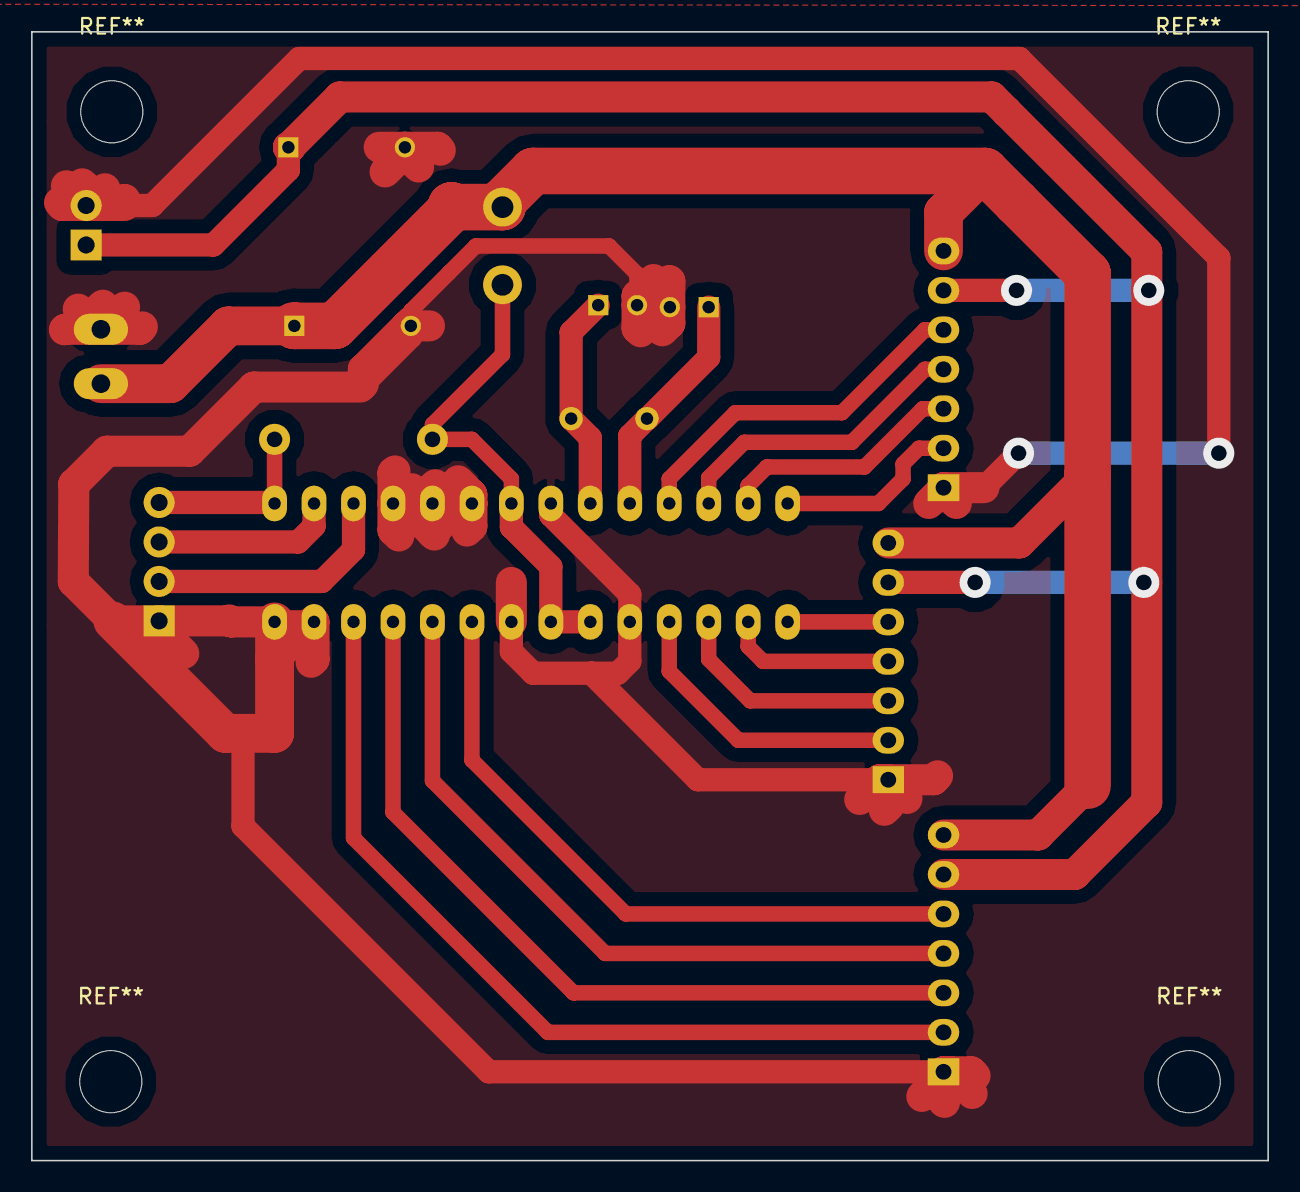
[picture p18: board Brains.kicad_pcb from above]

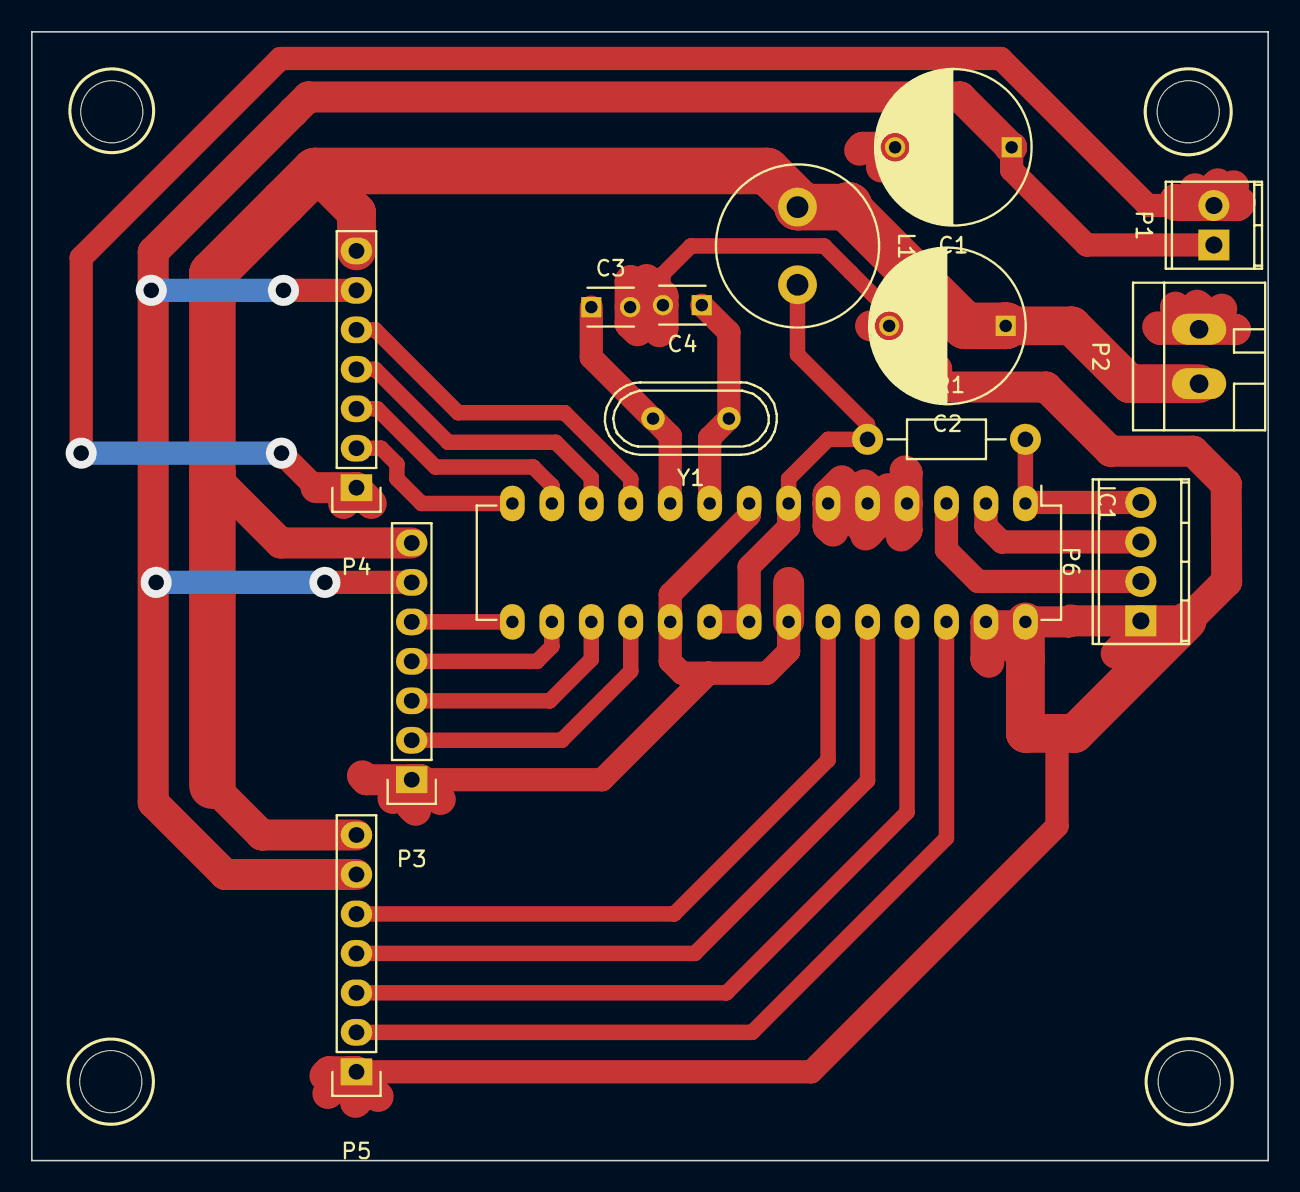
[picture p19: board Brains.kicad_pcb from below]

Board: 2 copper layers, 79.6 x 72.6 mm, 14 parts (14 on the bottom side), 21 nets.

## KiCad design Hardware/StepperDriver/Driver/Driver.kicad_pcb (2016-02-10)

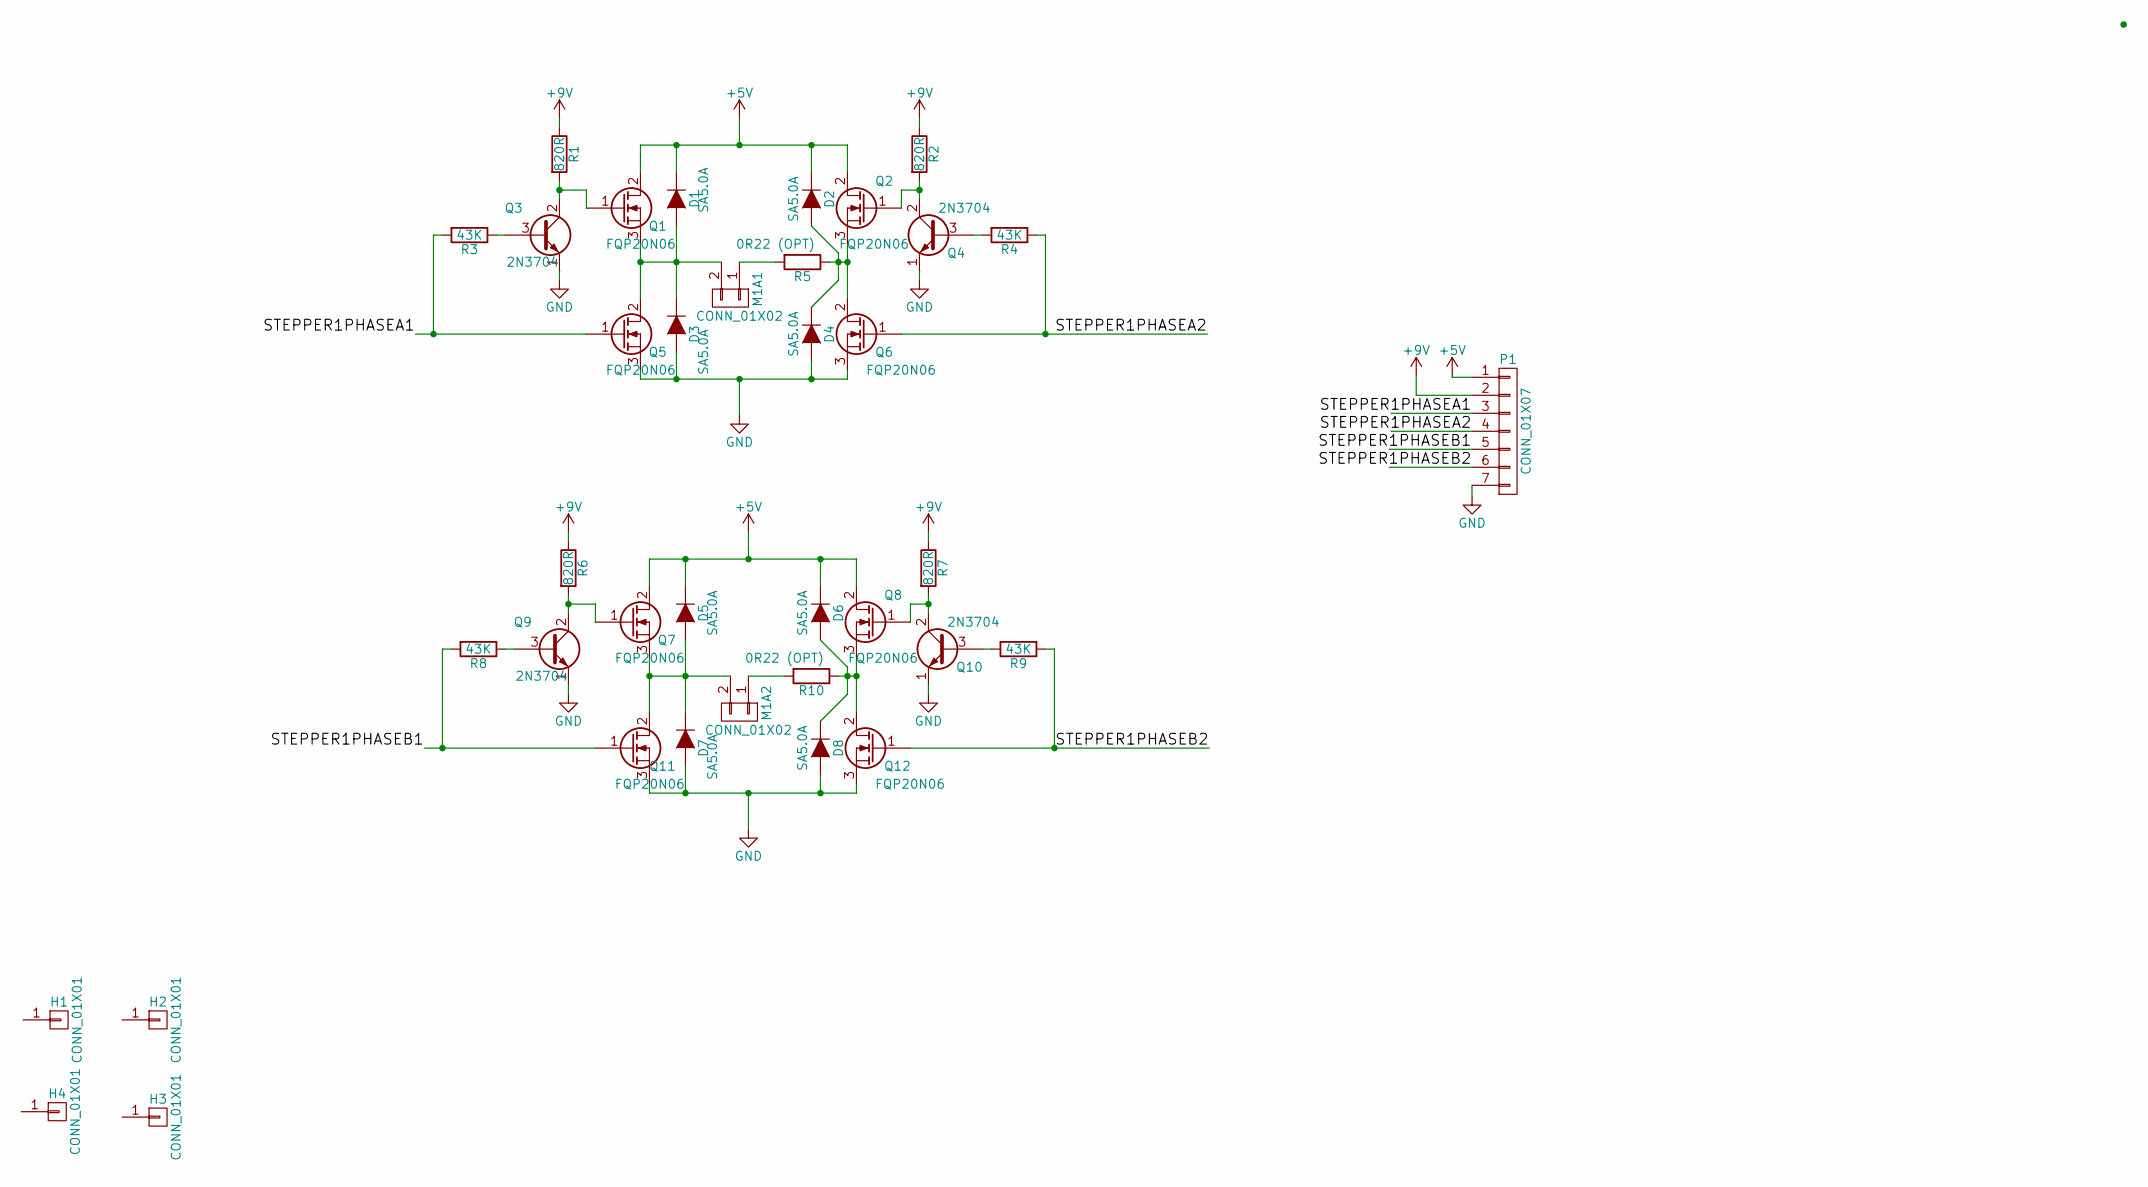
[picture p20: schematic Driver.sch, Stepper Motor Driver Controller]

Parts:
D1, D2, D3, D4, D5, D6, D7, D8: SA5.0A; Diode_DO-201AD_Horizontal_RM15
H1, H2, H3, H4: CONN_01X01; MountingHole_4mm
M1A1, M1A2: CONN_01X02; TerminalBlock_Pheonix_MPT-2.54mm_2pol
P1: CONN_01X07; Pin_Header_Straight_1x07
Q1, Q2, Q5, Q6, Q7, Q8, Q11, Q12: FQP20N06; TO-220_Neutral123_Horizontal_Reverse_LargePads
Q3, Q4, Q9, Q10: 2N3704; TO-92_Molded_Wide
R1, R2, R6, R7: 820R; Resistor_Horizontal_RM10mm
R3, R4, R8, R9: 43K; Resistor_Horizontal_RM10mm
R5, R10: 0R22 (OPT); Resistor_Cement_KOA-BGR-3N

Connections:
+5V: D1.1 (K), D2.1 (K), D5.1 (K), D6.1 (K), P1.1, Q1.2 (D), Q2.2 (D), Q7.2 (D), Q8.2 (D)
+9V: P1.2, R1.1, R2.1, R6.1, R7.1
/STEPPER1PHASEA1: P1.3, Q5.1 (G), R3.2
/STEPPER1PHASEA2: P1.4, Q6.1 (G), R4.1
/STEPPER1PHASEB1: P1.5, Q11.1 (G), R8.2
/STEPPER1PHASEB2: P1.6, Q12.1 (G), R9.1
GND: D3.2 (A), D4.2 (A), D7.2 (A), D8.2 (A), P1.7, Q3.1 (E), Q4.1 (E), Q5.3 (S), Q6.3 (S), Q9.1 (E), Q10.1 (E), Q11.3 (S), Q12.3 (S)
unnamed: D1.2 (A), D3.1 (K), M1A1.2, Q1.3 (S), Q5.2 (D)
unnamed: D2.2 (A), D4.1 (K), Q2.3 (S), Q6.2 (D), R5.1
unnamed: D5.2 (A), D7.1 (K), M1A2.2, Q7.3 (S), Q11.2 (D)
unnamed: D6.2 (A), D8.1 (K), Q8.3 (S), Q12.2 (D), R10.1
unnamed: M1A1.1, R5.2
unnamed: M1A2.1, R10.2
unnamed: Q1.1 (G), Q3.2 (C), R1.2
unnamed: Q2.1 (G), Q4.2 (C), R2.2
unnamed: Q3.3 (B), R3.1
unnamed: Q4.3 (B), R4.2
unnamed: Q7.1 (G), Q9.2 (C), R6.2
unnamed: Q9.3 (B), R8.1
unnamed: Q8.1 (G), Q10.2 (C), R7.2
unnamed: Q10.3 (B), R9.2

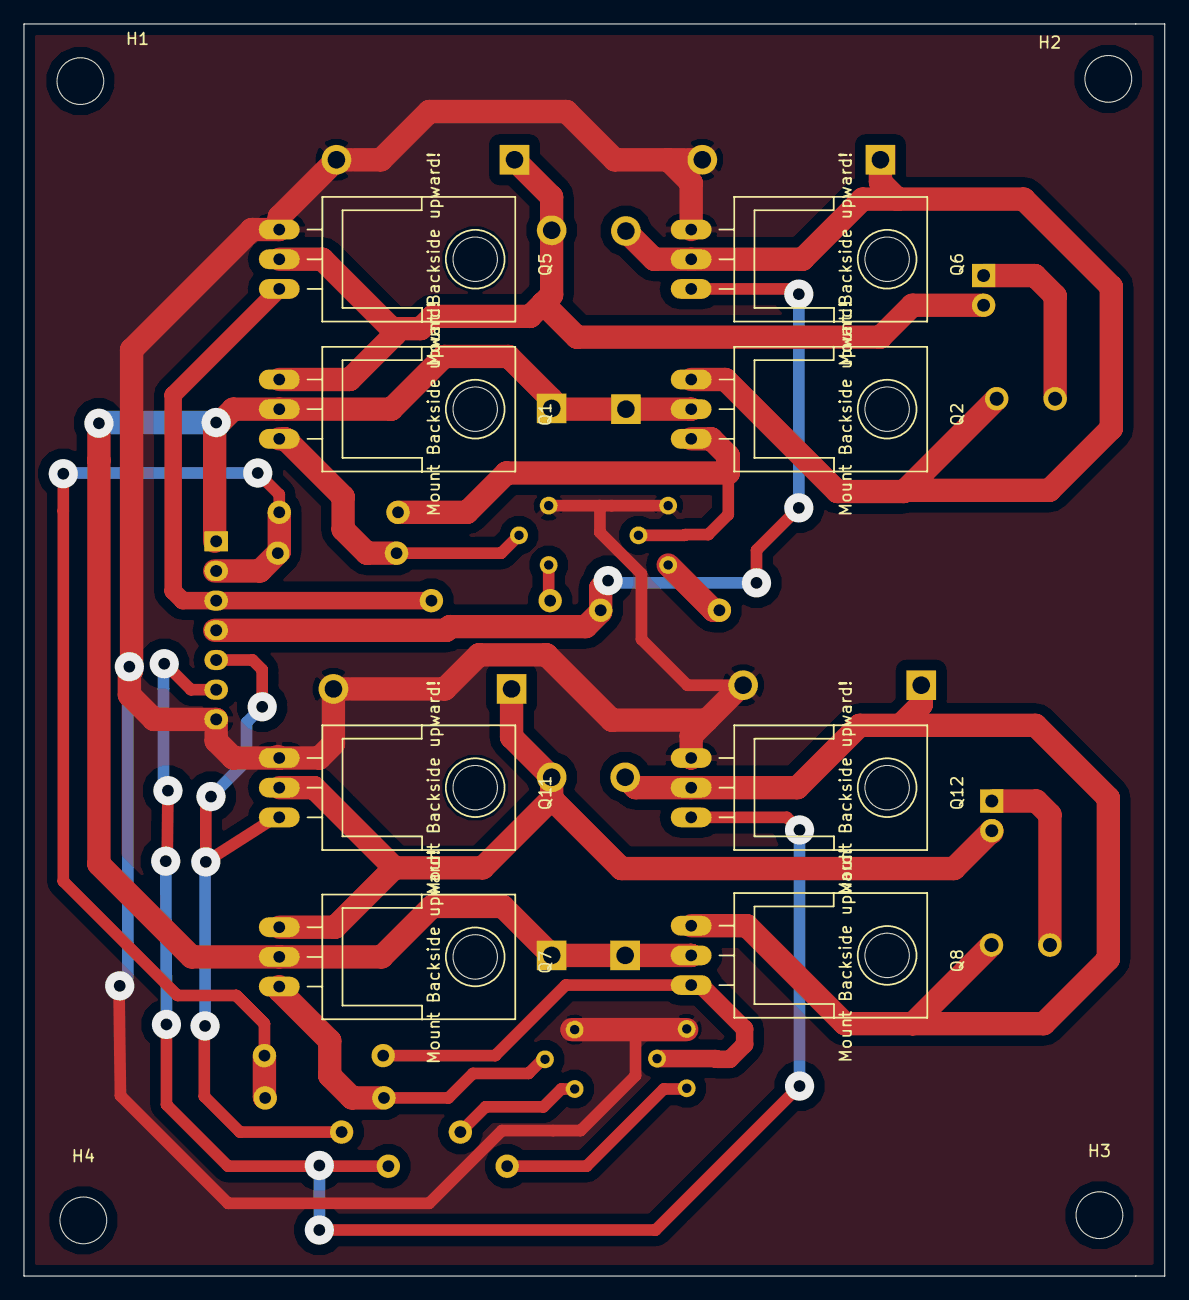
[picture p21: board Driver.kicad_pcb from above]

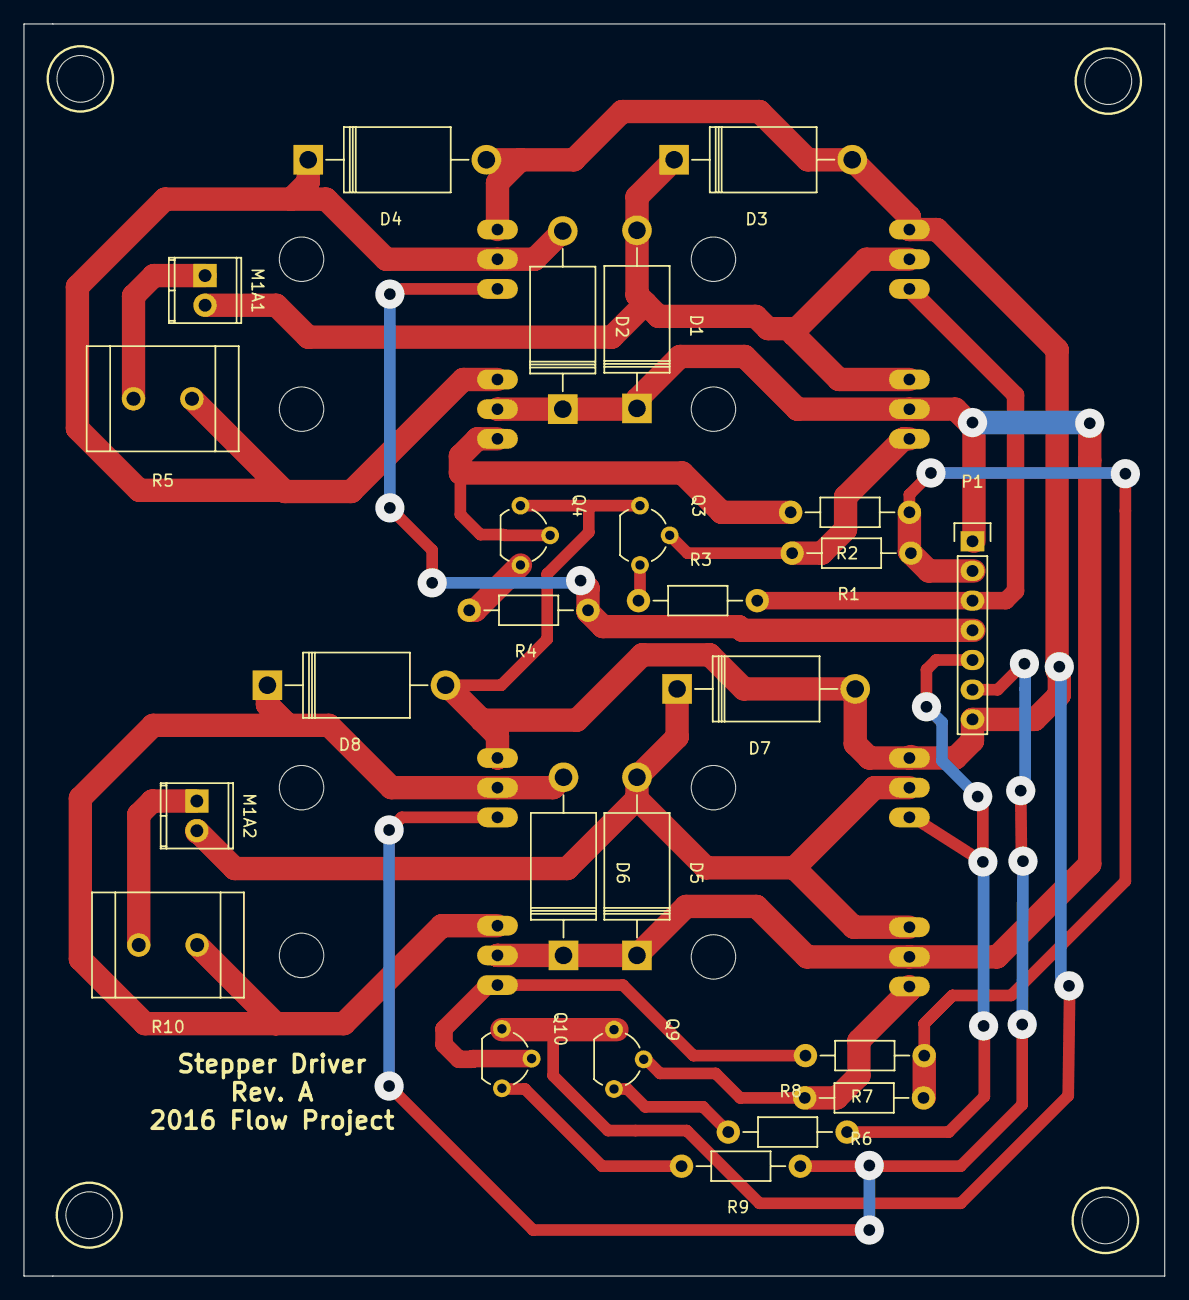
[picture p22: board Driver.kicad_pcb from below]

Board: 2 copper layers, 97.6 x 107.1 mm, 37 parts (25 on the bottom side), 21 nets.

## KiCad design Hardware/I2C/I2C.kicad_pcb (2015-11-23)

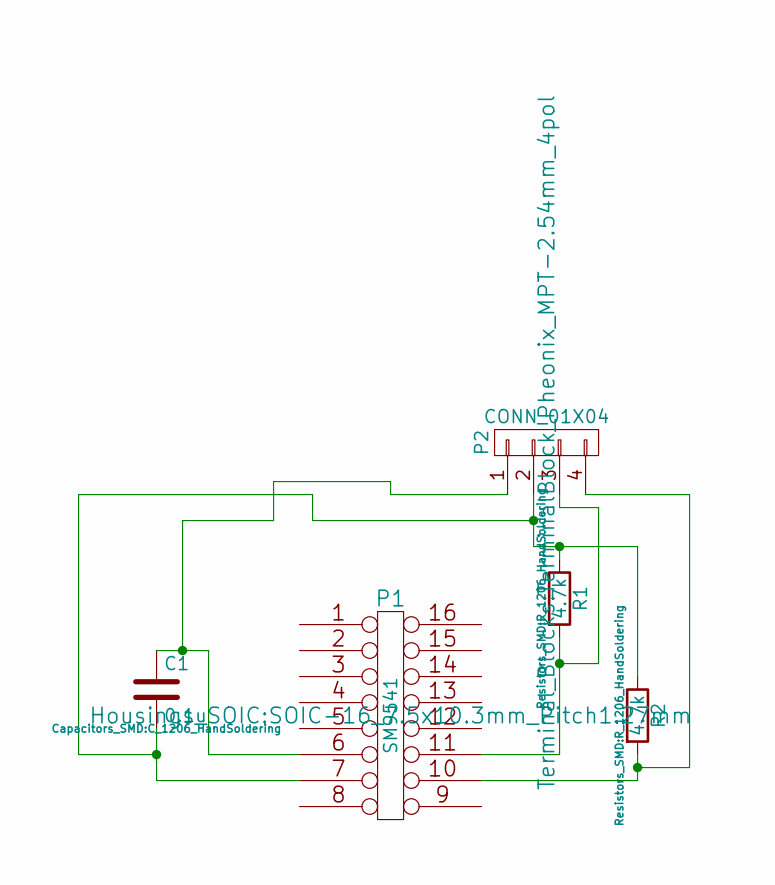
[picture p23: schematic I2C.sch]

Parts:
C1: 0.1u; C_1206_HandSoldering
P1: SM9541; SOIC-16_7.5x10.3mm_Pitch1.27mm
P2: CONN_01X04; TerminalBlock_Pheonix_MPT-2.54mm_4pol
R1, R2: 4.7k; R_1206_HandSoldering

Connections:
unnamed: C1.1, P1.6, P2.1
unnamed: C1.2, P1.7, P2.2, R1.1, R2.1
unnamed: P1.10, P2.4, R2.2
unnamed: P1.11, P2.3, R1.2

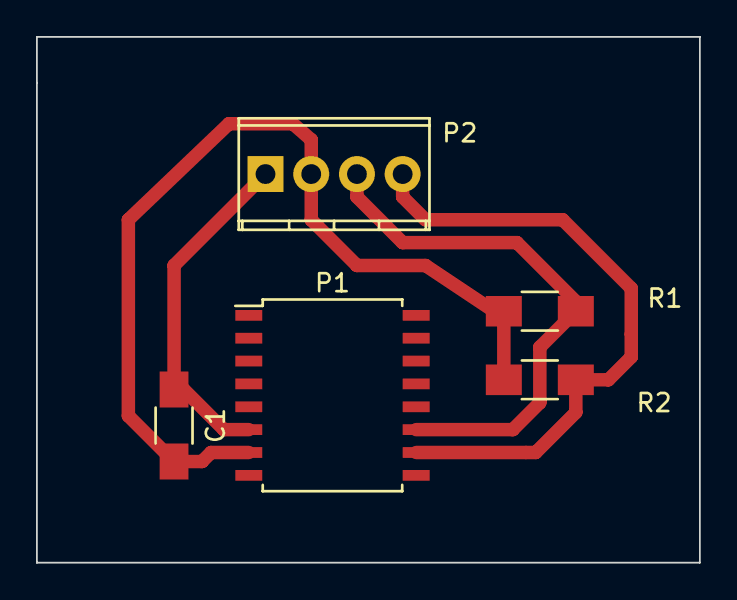
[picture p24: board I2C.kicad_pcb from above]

Board: 2 copper layers, 36.8 x 29.2 mm, 5 parts (0 on the bottom side), 4 nets.

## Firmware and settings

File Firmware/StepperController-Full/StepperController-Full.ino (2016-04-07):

/// This is a cut down version of the Stepper Firmware.
/// It offers ONLY FULL STEPPING but does actually work in both directions
/// it is mainly being used to test pruposes and to tweak the acceleration logic
/* stepper motor pins, NOTE ORDER: A1 B1 A2 B2 */
uint8_t XM1 = 9, XM2 = 11, XM3 = 10, XM4 = 12;
uint8_t YM1 = A0, YM2 = A2, YM3 = A1, YM4 = A3; // use analog pins for Y axis.
/* Limit switches, make sure to check at what end of end stop*/
uint8_t LimX = 7, LimY = 8;
/* min delay between each step change */
uint16_t minDelayTime = 1000, maxDelayTime = 5000;
/* what direction each motor rotates in */
uint8_t dirX, dirY;
#define DIR_LEFT 1
#define DIR_RIGHT 2

/* current phase/output of the stepper*/
uint8_t stepStatusX, stepStatusY;

/* command max length */
// MOTOR MODE SPEED DIRECTION DISTANCE HOLD
// 1     1    1     1          2 + 1    1   = 8
#define COMMAND_LENGTH 8


/* prototypes */
void zero();  // rotate each motor to one end until the limit switch is hit, now we know the posn.
void stepX(); // make the Xmotor step
void stepY(); // make the Ymotor step
uint8_t fourBitShiftRight(uint8_t val); // barrel shift right
uint8_t fourBitShiftLeft(uint8_t val);  // barrel shift left
void stopMotorX(); // disable output -- stops motor from being active
void stopMotorY(); // disable output -- stops motor from being active
uint16_t updateDelay(uint64_t totalStep, uint64_t currentStep, uint16_t currentDelay); // calculate the next delay.
void longDelay(uint16_t usDelay); // a delay routine that ACTUALLY WORKS......hurumph - crappy arduino delay don't work.

// step program initialises serial connection and Zeroes (no hold) axes.
void setup() {
  Serial.begin(76800);
  Serial.println("STEPPER V1. ENTER CONFIG");
  while (Serial.available() == 0) {} // wait for serial data
  minDelayTime = Serial.parseFloat() * 1000;
  maxDelayTime = Serial.parseFloat() * 1000;
  if (Serial.parseInt() ==1)
    dirX = DIR_LEFT;
  else
    dirX = DIR_RIGHT;
  if (Serial.parseInt() ==1)
    dirY = DIR_LEFT;
  else
    dirY = DIR_RIGHT; // down
  Serial.println(minDelayTime, DEC);
  Serial.println(maxDelayTime, DEC);
  //sanity check that configuration is ok.
  if (minDelayTime > 0)
    Serial.println("OK WAIT");




  //Setup ports
  pinMode(XM1, OUTPUT);
  pinMode(XM2, OUTPUT);
  pinMode(XM3, OUTPUT);
  pinMode(XM4, OUTPUT);
  pinMode(YM1, OUTPUT);
  pinMode(YM2, OUTPUT);
  pinMode(YM3, OUTPUT);
  pinMode(YM4, OUTPUT);
  pinMode(LimX, INPUT);
  pinMode(LimY, INPUT);
  /* set pullups on limit switches */
  digitalWrite(LimX, HIGH);
  digitalWrite(LimY, HIGH);

  // initialise motor states
  stepStatusX = 0B0011;
  stepStatusY = 0B0011;
  // zero the aixs
  Serial.println("ZEROING ALL AXES");
  zero();
  Serial.println("ZEROED");
  // tell the program we are ready to take commands
  while (Serial.available() != 0) {
    Serial.read(); // make sure serial buffer is empty.
  }
  Serial.println("OK WAIT");
}

void zero()
{
  // for each axis step all the way until a limit is met.
  //while limit switch is not triggered, keep stepping.
  while (digitalRead(LimX) == 1)
  {
    stepX(); // step
    longDelay(minDelayTime+ 200); // wait min delay time + some room
  }
  stopMotorX();
  while (digitalRead(LimY) == 1)
  {
    stepY();
    longDelay(minDelayTime + 200);
  }
  stopMotorY();
}

uint8_t fourBitShiftRight(uint8_t val)
{
  return   (((val & 0B1000) >> 3) | (val << 1 )) & 0B1111; // take the left hand digit, insert it on the right.
}
uint8_t fourBitShiftLeft(uint8_t val)
{
  return   ((((val & 0B1) << 3) & 0b1000) | ((val >> 1 ) & 0b0111)) & 0B1111; // take the left hand digit, insert it on the right.
}

void stepX()
{
  //  Simply shift output.
  if (dirX == DIR_LEFT)
  {
    stepStatusX = fourBitShiftLeft(stepStatusX);
    Serial.println("XL");
  }
  else
  {
    stepStatusX = fourBitShiftRight(stepStatusX);
    Serial.println("XR");
  }
  // and output the new motor poles
  digitalWrite(XM1, (stepStatusX & 0B1000) >> 3);
  digitalWrite(XM2, (stepStatusX & 0B0100) >> 2);
  digitalWrite(XM3, (stepStatusX & 0B0010) >> 1);
  digitalWrite(XM4, (stepStatusX & 0B0001));
}
void stepY()
{
  // Simply shift output.
  if (dirY == DIR_LEFT)
  {
    stepStatusY = fourBitShiftLeft(stepStatusY);
    Serial.println("YL");
  }
  else
  {
    stepStatusY = fourBitShiftRight(stepStatusY);
    Serial.println("YR");
  }
  // output the new motor state
  digitalWrite(YM1, (stepStatusY & 0B1000) >> 3);
  digitalWrite(YM2, (stepStatusY & 0B0100) >> 2);
  digitalWrite(YM3, (stepStatusY & 0B0010) >> 1);
  digitalWrite(YM4, (stepStatusY & 0B0001));
}
void stopMotorX()
{
  // If motor state is left, the coils will remain energised so we stop it.
  digitalWrite(XM1, LOW);
  digitalWrite(XM2, LOW);
  digitalWrite(XM3, LOW);
  digitalWrite(XM4, LOW);
}
void stopMotorY()
{
  // If motor state is left, the coils will remain energised so we stop it.
  digitalWrite(YM1, LOW);
  digitalWrite(YM2, LOW);
  digitalWrite(YM3, LOW);
  digitalWrite(YM4, LOW);
}
void loop() {
  byte command[COMMAND_LENGTH];
  // initialise to zero
  for (uint8_t val = 0; val <= (COMMAND_LENGTH - 1); val ++)
    command[val] = 0x00;

  uint8_t hasWholeCommand = 0;
  uint8_t charCount = 0;
  while (0 == hasWholeCommand)
  {
    while (0 == Serial.available()) {} // wait for at least one byte of data.
    byte charIn = Serial.read(); // read 1 byte
    if (charCount < (COMMAND_LENGTH - 1))
    {
      command[charCount] = charIn;
      charCount++;
    }
    else if ('\n' == charIn) // if we received last character and have a full compliment of data
      hasWholeCommand = 1; //set flag to show we have whole payload
  }
  if (command[0] == 0x00)
    return; // the command is blank, quit this loop.
  /*
   * ACTUALLY PROCESS THE COMMAND
   */
  // get the total number of revs and steps requested.
  uint16_t revs = 0;
  revs = (command[4] << 8) | command[5];
  uint8_t steps = 0;
  steps = command[6];
  uint64_t totalStep = 0;
  totalStep = (revs * 200) + steps;
  if (totalStep != 0)
  {
    if (command[0] == 0x1) // motorX
    {
      if (command[3] == 0x1) // LEFT
        dirX = DIR_LEFT;
      else if (command[3] == 0x2) // RIGHT
        dirX = DIR_RIGHT;

      //actually step the motor
      if (command[2] == 0x1) // FAST
      {
        for ( uint64_t rev = 1; rev <= totalStep; rev++)
        {
          stepX();
          longDelay(minDelayTime);
        }
      }
      else if (command[2] == 0x2) // SLOW
        for ( uint64_t rev = 1; rev <= totalStep; rev++)
        {
          stepX();
          longDelay(maxDelayTime);
        }
      else if (command[2] == 0x3) // DYNAMIC
      {
        uint16_t currentDelay = maxDelayTime;
        for ( uint64_t currentStep = 1; currentStep <= totalStep; currentStep++)
        {
          currentDelay = updateDelay(totalStep, currentStep, currentDelay);
          stepX();
          longDelay(currentDelay);
        }
      }
      if (command[7] != 0x00)
      {
        delay(command[7]);
      }
      stopMotorX();
    }
    else if (command[0] == 0x2) //motorY
    {
      if (command[3] == 0x1) // LEFT
        dirY = DIR_LEFT;
      else if (command[3] == 0x2) // RIGHT
        dirY = DIR_RIGHT;

      //actually step the motor
      if (command[2] == 0x1) // FAST
        for ( uint64_t rev = 1; rev <= totalStep; rev++)
        {
          stepY();
          longDelay(minDelayTime);
        }
      else if (command[2] == 0x2) // SLOW
        for ( uint64_t rev = 1; rev <= totalStep; rev++)
        {
          stepY();
          longDelay(maxDelayTime);
        }
      else if (command[2] == 0x3) // DYNAMIC
      {
        uint16_t currentDelay = maxDelayTime;
        for ( uint64_t currentStep = 1; currentStep <= totalStep; currentStep++)
        {
          currentDelay = updateDelay(totalStep, currentStep, currentDelay);
          stepY();
          longDelay(currentDelay);
        }
      }
      if (command[7] != 0x00)
      {
        delay(command[7]);
      }
      stopMotorY();
    }
  }
  Serial.println("OK DONE");
}

uint16_t updateDelay(uint64_t totalStep, uint64_t currentStep, uint16_t currentDelay)
{
  if (currentStep > (totalStep - 26))
  {
    if (currentDelay < maxDelayTime)
      return currentDelay + 100;
    else
      return maxDelayTime;
  }
  else if (currentStep < 26)
  { // accelerate
    if (currentDelay > minDelayTime)
      return currentDelay - 100;
    else
      return minDelayTime;
  }
  else
    return currentDelay;
}
void longDelay(uint16_t usDelay) // the arduino delayMicros has a massive bug where it will cause an issue if delay for more than 10ms.
{
  uint16_t millisCount = usDelay / 1000; // get the number of milliseconds
  uint16_t microsCount = usDelay % 1000;// get number of micros, by finding remainder when dividing by 1ms.
  delay(millisCount);
  delayMicroseconds(microsCount);
}

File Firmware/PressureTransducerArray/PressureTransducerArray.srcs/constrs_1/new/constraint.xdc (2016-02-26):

# apparently need this:
set_property CFGBVS VCCO [current_design]
set_property CONFIG_VOLTAGE 3.3 [current_design]






##Pmod Header JA
##Bank = 15, Pin name = IO_L1N_T0_AD0N_15,					Sch name = JA1
set_property PACKAGE_PIN B13 [get_ports {SCL1}]					
	set_property IOSTANDARD LVCMOS33 [get_ports {SCL1}]
##Bank = 15, Pin name = IO_L5N_T0_AD9N_15,					Sch name = JA2
set_property PACKAGE_PIN F14 [get_ports {SCL2}]					
	set_property IOSTANDARD LVCMOS33 [get_ports {SCL2}]
##Bank = 15, Pin name = IO_L16N_T2_A27_15,					Sch name = JA3
set_property PACKAGE_PIN D17 [get_ports {SCL3}]					
	set_property IOSTANDARD LVCMOS33 [get_ports {SCL3}]
##Bank = 15, Pin name = IO_L16P_T2_A28_15,					Sch name = JA4
set_property PACKAGE_PIN E17 [get_ports {SCL4}]					
	set_property IOSTANDARD LVCMOS33 [get_ports {SCL4}]
##Bank = 15, Pin name = IO_0_15,								Sch name = JA7
set_property PACKAGE_PIN G13 [get_ports {SDA1}]					
	set_property IOSTANDARD LVCMOS33 [get_ports {SDA1}]
##Bank = 15, Pin name = IO_L20N_T3_A19_15,					Sch name = JA8
set_property PACKAGE_PIN C17 [get_ports {SDA2}]					
	set_property IOSTANDARD LVCMOS33 [get_ports {SDA2}]
##Bank = 15, Pin name = IO_L21N_T3_A17_15,					Sch name = JA9
set_property PACKAGE_PIN D18 [get_ports {SDA3}]					
	set_property IOSTANDARD LVCMOS33 [get_ports {SDA3}]
##Bank = 15, Pin name = IO_L21P_T3_DQS_15,					Sch name = JA10
set_property PACKAGE_PIN E18 [get_ports {SDA4}]					
	set_property IOSTANDARD LVCMOS33 [get_ports {SDA4}]


##Pmod Header JB
##Bank = 15, Pin name = IO_L15N_T2_DQS_ADV_B_15,				Sch name = JB1
set_property PACKAGE_PIN G14 [get_ports {SCL5}]					
	set_property IOSTANDARD LVCMOS33 [get_ports {SCL5}]
##Bank = 14, Pin name = IO_L13P_T2_MRCC_14,					Sch name = JB2
set_property PACKAGE_PIN P15 [get_ports {SCL6}]					
	set_property IOSTANDARD LVCMOS33 [get_ports {SCL6}]
##Bank = 14, Pin name = IO_L21N_T3_DQS_A06_D22_14,			Sch name = JB3
set_property PACKAGE_PIN V11 [get_ports {SCL7}]					
	set_property IOSTANDARD LVCMOS33 [get_ports {SCL7}]
##Bank = CONFIG, Pin name = IO_L16P_T2_CSI_B_14,				Sch name = JB4
set_property PACKAGE_PIN V15 [get_ports {SCL8}]					
	set_property IOSTANDARD LVCMOS33 [get_ports {SCL8}]
##Bank = 15, Pin name = IO_25_15,							Sch name = JB7
set_property PACKAGE_PIN K16 [get_ports {SDA5}]					
	set_property IOSTANDARD LVCMOS33 [get_ports {SDA5}]
##Bank = CONFIG, Pin name = IO_L15P_T2_DQS_RWR_B_14,			Sch name = JB8
set_property PACKAGE_PIN R16 [get_ports {SDA6}]					
	set_property IOSTANDARD LVCMOS33 [get_ports {SDA6}]
##Bank = 14, Pin name = IO_L24P_T3_A01_D17_14,				Sch name = JB9
set_property PACKAGE_PIN T9 [get_ports {SDA7}]					
	set_property IOSTANDARD LVCMOS33 [get_ports {SDA7}]
##Bank = 14, Pin name = IO_L19N_T3_A09_D25_VREF_14,			Sch name = JB10 
set_property PACKAGE_PIN U11 [get_ports {SDA8}]					
	set_property IOSTANDARD LVCMOS33 [get_ports {SDA8}]


##Pmod Header JC
##Bank = 35, Pin name = IO_L23P_T3_35,						Sch name = JC1
set_property PACKAGE_PIN K2 [get_ports {SCL9}]					
	set_property IOSTANDARD LVCMOS33 [get_ports {SCL9}]
##Bank = 35, Pin name = IO_L6P_T0_35,						Sch name = JC2
set_property PACKAGE_PIN E7 [get_ports {SCL10}]					
	set_property IOSTANDARD LVCMOS33 [get_ports {SCL10}]
##Bank = 35, Pin name = IO_L22P_T3_35,						Sch name = JC3
#set_property PACKAGE_PIN J3 [get_ports {JC[2]}]					
	#set_property IOSTANDARD LVCMOS33 [get_ports {JC[2]}]
##Bank = 35, Pin name = IO_L21P_T3_DQS_35,					Sch name = JC4
#set_property PACKAGE_PIN J4 [get_ports {JC[3]}]					
	#set_property IOSTANDARD LVCMOS33 [get_ports {JC[3]}]
##Bank = 35, Pin name = IO_L23N_T3_35,						Sch name = JC7
set_property PACKAGE_PIN K1 [get_ports {SDA9}]					
	set_property IOSTANDARD LVCMOS33 [get_ports {SDA9}]
##Bank = 35, Pin name = IO_L5P_T0_AD13P_35,					Sch name = JC8
set_property PACKAGE_PIN E6 [get_ports {SDA10}]					
	set_property IOSTANDARD LVCMOS33 [get_ports {SDA10}]
##Bank = 35, Pin name = IO_L22N_T3_35,						Sch name = JC9
#set_property PACKAGE_PIN J2 [get_ports {JC[6]}]					
	#set_property IOSTANDARD LVCMOS33 [get_ports {JC[6]}]
##Bank = 35, Pin name = IO_L19P_T3_35,						Sch name = JC10
#set_property PACKAGE_PIN G6 [get_ports {JC[7]}]					
	#set_property IOSTANDARD LVCMOS33 [get_ports {JC[7]}]
	
	## Clock signal
    ##Bank = 35, Pin name = IO_L12P_T1_MRCC_35,                    Sch name = CLK100MHZ
    set_property PACKAGE_PIN E3 [get_ports clk]                            
        set_property IOSTANDARD LVCMOS33 [get_ports clk]
        create_clock -add -name sys_clk_pin -period 10.00 -waveform {0 5} [get_ports clk]
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

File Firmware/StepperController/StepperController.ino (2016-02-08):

/* stepper motor pins, NOTE ORDER: A1 B1 A2 B2 */
uint8_t XM1 = 9, XM2 = 11, XM3 = 10, XM4 = 12;
uint8_t YM1 = A0, YM2 = A2, YM3 = A1, YM4 = A4; // use analog pins for Y axis.
/* Limit switches, make sure to check at what end of end stop*/
uint8_t LimX = 7, LimY = 8;
/* min delay between each step change */
uint16_t minDelayTime = 1000, maxDelayTime = 5000;
/* what direction each motor rotates in */
uint8_t dirX, dirY;
#define DIR_LEFT 1
#define DIR_RIGHT 2
/* what mode the stepper motor is controlled as */
uint8_t modeX, modeY;
#define STEP_WAVE 1
#define STEP_FULL 2
#define STEP_HALF 3

/* current phase/output of the stepper*/
uint8_t stepStatusX, stepStatusY;
/* if half stepping, we need some extra variables - the previous state */
uint8_t lastHalfStepX, lastHalfStepY;

/* command max length */
// MOTOR MODE SPEED DIRECTION DISTANCE
// 1      1    1       1        2 + 1 = 7
#define MAX_COMMAND_LENGTH 7 


/* prototypes */
void zero();  // rotate each motor to one end until the limit switch is hit, now we know the posn.
void stepX(); // make the Xmotor step
void stepY(); // make the Ymotor step
uint8_t fourBitShiftRight(uint8_t val); // barrel shift right
uint8_t fourBitShiftLeft(uint8_t val);  // barrel shift left
void stopMotorX(); // disable output -- stops motor from being active
void stopMotorY(); // disable output -- stops motor from being active

// step program initialises serial connection and Zeroes (no hold) axes.
void setup() {
  Serial.begin(9600);
  Serial.println("HELLO, PLEASE ENTER CONFIG SETTINGS: MINDELAY (=1) MAXDELAY (=10)");
  while (Serial.available() ==0) {} // wait for serial data
  minDelayTime = Serial.parseInt();
  maxDelayTime = Serial.parseInt();
  //sanity check that configuration is ok.
 if (minDelayTime > 0)
    Serial.println("OK WAIT");  
 //Setup ports
  pinMode(XM1, OUTPUT);
  pinMode(XM2, OUTPUT);
  pinMode(XM3, OUTPUT);
  pinMode(XM4, OUTPUT);
  pinMode(YM1, OUTPUT);
  pinMode(YM2, OUTPUT);
  pinMode(YM3, OUTPUT);
  pinMode(YM4, OUTPUT);
  pinMode(LimX, INPUT);
  pinMode(LimY, INPUT);
  /* set pullups on limit switches */
  digitalWrite(LimX, HIGH);
  digitalWrite(LimY, HIGH);

  /* intialise all motor states */
  modeX = STEP_HALF; // default to half wave drive
  modeY = STEP_HALF; // default to half wave drive
  // initialise motor states
  lastHalfStepX = 0B1001; stepStatusX = 0B0001;
  lastHalfStepY = 0B1001; stepStatusY = 0B0001; 
  // zero the aixs
  Serial.println("ZEROING ALL AXES");
  zero();
  // tell the program we are ready to take commands
  Serial.println("OK READY");
}

void zero()
{
  // for each axis step all the way until a limit is met.
  dirX = DIR_RIGHT;
  dirY = DIR_LEFT;
  //while limit switch is not triggered, keep stepping.
  while (digitalRead(LimX) == 1)
  {
    stepX(); // step
    delayMicroseconds(minDelayTime); // wait min delay time
  }
  stopMotorX();
  while (digitalRead(LimY) == 1)
  {
    stepY();
    delayMicroseconds(minDelayTime);
  }
  stopMotorY();
}

uint8_t fourBitShiftRight(uint8_t val)
{
  return   (((val & 0B1000) >> 3) | (val << 1 )) & 0B1111; // take the left hand digit, insert it on the right.
}
uint8_t fourBitShiftLeft(uint8_t val)
{
  return   ((((val & 0B1) << 3) & 0b1000) | ((val >> 1 ) & 0b0111)) & 0B1111; // take the left hand digit, insert it on the right.
}

void stepX()
{
  if (modeX == STEP_HALF)// if half stepping, use a different routine
  {
     uint8_t currentstep = 0; // variable to hold new step
     if (dirX == DIR_LEFT)
      currentstep = fourBitShiftLeft(lastHalfStepX); // perform the shift on the previous state
     else
      currentstep = fourBitShiftRight(lastHalfStepX);
     lastHalfStepX = stepStatusX; // put the current state into the previous state variable
     stepStatusX = currentstep; // load up the new current state
  }
  else
  {
    // WAVE STEP AND FULL STEP, Simply shift output.
    if (dirX == DIR_LEFT)
      stepStatusX = fourBitShiftLeft(stepStatusX);
    else
      stepStatusX = fourBitShiftRight(stepStatusX);
  }
  // and output the new motor poles
digitalWrite(XM1, (stepStatusX & 0B1000) >> 3);
digitalWrite(XM2, (stepStatusX & 0B0100) >> 2);
digitalWrite(XM3, (stepStatusX & 0B0010) >> 1);
digitalWrite(XM4, (stepStatusX & 0B0001));
}
void stepY()
{
  if (modeY == STEP_HALF) // if half stepping use a different routine
  {
     uint8_t currentstep = 0; // variable to hold new step
     if (dirY == DIR_LEFT)
      currentstep = fourBitShiftLeft(lastHalfStepY); // perform shift on previous state
     else
      currentstep = fourBitShiftRight(lastHalfStepY);
     lastHalfStepY = stepStatusY; // put the current state into the last state
     stepStatusY = currentstep; // update the output
  }
  else
  {
    // WAVE STEP AND FULL STEP, Simply shift output.
    if (dirY == DIR_LEFT)
      stepStatusY = fourBitShiftLeft(stepStatusY);
    else
      stepStatusY = fourBitShiftRight(stepStatusY);
  }
  // output the new motor state
digitalWrite(YM1, (stepStatusY & 0B1000) >> 4);
digitalWrite(YM2, (stepStatusY & 0B0100) >> 3);
digitalWrite(YM3, (stepStatusY & 0B0010) >> 2);
digitalWrite(YM4, (stepStatusY & 0B0001) >> 1);
}
void stopMotorX()
{
  // If motor state is left, the coils will remain energised so we stop it.
  digitalWrite(XM1, LOW);
  digitalWrite(XM2, LOW);
  digitalWrite(XM3, LOW);
  digitalWrite(XM4, LOW);
}
void stopMotorY()
{
  // If motor state is left, the coils will remain energised so we stop it.
  digitalWrite(YM1, LOW);
  digitalWrite(YM2, LOW);
  digitalWrite(YM3, LOW);
  digitalWrite(YM4, LOW);
}
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

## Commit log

2015-11-17 added Arduino Example of simple stepper motor control
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2015-11-17 created intial I2C mockup for SLM9541
    [I2C.kicad_pcb, I2C.sch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]
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2015-11-23 updated I2C design, added various exports used in testing with cnc machine
    [I2C-B_Cu.dxf, I2C-F_Cu.dxf, I2C-F_Cu_ISOLATION_GCODE.dxf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]
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2015-11-23 begun work on stepper driver schematic
    [StepperDriver.kicad_pcb, StepperDriver.sch]
2015-11-23 begun work on hot wire schematic
    [HotWire.kicad_pcb, HotWire.sch]
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2015-12-03 updated schematic for 2 motors
    [StepperDriver.sch]
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2015-12-03 added component values. Updated for 3 motor design
    [StepperDriver.sch]
2015-12-03 added missing diode values, added motor connectors. Exported Schematic to PDF
    [StepperDriver.sch]
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2016-01-17 initial mockup of single channel driver
    [HighPower.sch, StepperDriver.kicad_pcb, StepperDriver.sch]
2016-01-25 updated to modularised design and initial draft of production layout
    [Brains.kicad_pcb, Brains.sch, Driver.kicad_pcb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]
2016-01-25 various production tweaks: fixed track layers and footprints
    [Brains.kicad_pcb, Brains.sch, Driver.kicad_pcb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]
2016-01-25 added various pictures of PCB
    [Driver.kicad_pcb]
2016-01-26 created main project file for schematics. exported design files to pdf and dxf
    [Brains-F.Cu.dxf, Brains.kicad_pcb, Brains.sch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]
2016-01-27 initial commit of bugged code
    [constraint.xdc]
2016-01-28 updated contstrains to fix warning when generating bitstream
    [constraint.xdc]
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2016-02-02 fixed incorrect Xtal footprint
    [Brains.kicad_pcb, Brains.sch]
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2016-02-04 updated pins to match schematics updated delay variables to set max speed and min speed added initial command structure tidied serial init routine and default to wave drive stepper converted to micro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
    [StepperController.ino]
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2016-02-08 fixed incorrect initialisation value for half step tidied shift left operation ( added masking) added calculation of totalSteps - 400 or 200 per rev depending on mode fixed incorrect count of steps f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
    [StepperController.ino]
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2016-02-10 added quick and dirty keepout zones to the solder Resist layer added board identification text added alignment marks to other layers (solder resist + Silk)
    [Driver.kicad_pcb]
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2016-02-12 added new DataSequencer module to link buffers. - will eventually sort all buffers changed finishFlag to ByteCount to allow for better functionality. added delimeter to each read operation
    Added simulation source to test module with I2C device fake ACK.
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2016-02-22 added silkscreen hole outline
    [Brains.kicad_pcb]
2016-02-22 moved from dispatcher driven threading to queue & worker process. Started using cleaner commands.
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2016-02-23 removed old pressure calculation as results not accurate enough. made isConnected public. updated file dumps to have .DAT extensions. completely re-wrote data handling mechanism
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2016-02-25 temporarily removed unused ports. updated to use correct ports for SCL and SDA. Removed rw and addr from I2C control as constant so will not need changing.
    [constraint.xdc]
2016-02-25 updated pinout to be compatible with array PCB and also used pin names featuring sensorID
2016-02-26 updated Pressure Data class to more appropriate names, also added additional data elements. updated processing routine to process new 6 byte header.Also added better header handling - for future upda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
2016-02-27 completely re-wrote to remove multiplexers. Seems to have stabilised the sensor array packets and removed a lot of warnings in synthesis.
2016-02-27 mods to stepper controller: removed unused dispatcher added ViewModelBase helper class converted isConnected and isBusy to properties with notifications
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2016-02-27 added lastest sensor reading properties with update. added regions added connection state property with update. removed dispatcher allocation on creation and moved to set dispatcher routine added rou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
2016-02-27 updated main view to show current sensor readings and status. wired up additional buttons
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2016-03-01 added check to make sure stepper controller was connected before sending job commands. removed dispatcher assignment. added timer to update UI elements
2016-03-01 added moment (datetime reading) and Id (unique number) to pressure data class.
2016-03-01 created hotwire ADC pcb project
    [HotWireADC.kicad_pcb, HotWireADC.sch]
2016-03-02 created custom part for ADC component.
    [HotWireADC.sch]
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2016-03-04 increased timeout window to prevent multiple loops, also removed timeout from sensor 1. this fixes timing of the loops, but means that sensor 1 will ALWAYS have to be connected
2016-03-11 moved HotWireADC hardware files to revision structure - due to complete design change
    [HotWireADC.kicad_pcb, HotWireADC.sch]
2016-03-12 created initial design and added relevant datasheets
    [HotWireRev2.kicad_pcb, HotWireRev2.sch]
2016-03-12 fixed incorrect sensor count update. made serialiser buffer bigger fixed typo on temperature calculation
2016-03-13 added footprints to schematic
    [HotWireRev2.sch]
2016-03-13 created intial PCB layout
    [HotWireRev2.kicad_pcb, HotWireRev2.sch]
2016-03-13 moved external reference to BNC connector & tidied layout
    [HotWireRev2.kicad_pcb, HotWireRev2.sch]
2016-03-13 updated regulator footprint and removed additional regulator
    [HotWireRev2.kicad_pcb, HotWireRev2.sch]
2016-03-13 updated component names and created BOM
    [BOMHotWireRev2.xlsx, HotWireRev2.sch]
2016-03-13 increased track widths.
    [HotWireRev2.kicad_pcb]
2016-03-14 added parts needed for BOM + parts from other HotWire hardware ( maintained by different user)
    [BOMHotWireRev2.xlsx]
2016-03-14 tidied layout added text to silk added mounting holes and alignment marks
    [HotWireRev2.kicad_pcb]
2016-03-15 switched to custom delay routine due to arduino delay functions being so bad
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2016-03-17 updated positional data to read in microns fixed axis typo. set motor to not move after axis zero.
2016-03-17 moved controllers to automation container. made automationcontroller use background worker to keep UI thread responsive. moved some properties to the automationcontroller
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2016-04-03 added quick fix to see if stepper motor controller is connected and implemented settle time wait
2016-04-04 increased serial speed. added fix to ask for limit location when initialising
    [StepperController-Full.ino]
2016-04-04 updated stepper baud rate and updated a lot of hard coded values to constants. added limit location functionality. fixed Y axis direction issue.
2016-04-04 changed pressureexport data to long - to account for long running times
2016-04-04 added busy flag to automation controller. took advantage of pressure export id continuation function. fixed missing delimeter on export. added check to prevent creation of empty files.
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2016-04-06 updated schematic to use correct DC jack footprint
    [HotWireRev2.sch]
2016-04-06 implemented new DC jack footprint
    [HotWireRev2.kicad_pcb]
2016-04-07 shortened acceleration time in stepper algorithm
    [StepperController-Full.ino]
2016-04-10 changed location of zero on axis. reduced motor delay -- imcreased motor speed. disabled Console updates of serial log
2016-04-10 added atmospheric pressures and temperatures to VM and export. removed background worker and replaced with async method to get better timing of system. changed from foreach to index array addressing 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
    Updated UI to use new async automation method.
2016-04-10 ensured current sensor readings - by setting readings to 0 before processing readings recreated queue to allow for re-connections
2016-04-11 added extra marks and alignment to PCB for silkscreen
    [HotWireRev2.kicad_pcb]
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2016-04-15 added pause capability. Added check to only request to update stepper motors if needed. move sensor acquisition to try catch expression to recover from bad readings
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2016-05-04 tidied git folder, added commenting to code
    [Git History.xlsx, HotWire.kicad_pcb, HotWire.sch]

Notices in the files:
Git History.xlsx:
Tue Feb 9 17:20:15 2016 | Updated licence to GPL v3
